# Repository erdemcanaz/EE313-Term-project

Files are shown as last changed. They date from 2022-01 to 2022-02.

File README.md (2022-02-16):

<h1 align="center" style=" border-bottom: none ;">Implementing An Analog Approach For Closed Environment Autonomous Temperature Control Circuitry </h1>
<h3 align="center" style="font-style: italic;font-size:2em;">  EE-313 TERM PROJECT </h3>

<h3 align="center" style="font-style: italic;font-size:2em;">  General requirements </h3>

<p>The project consists of five units; namely, <b>sensing, set, control, operation and display units</b>. The sensing unit perceives the ambient temperature and sends this information to the control and display units. Similarly, set unit receives an input from the user indicating the desired temperature level and send this information to control and display units. Control unit compares the two temperatures and decides the action to be taken by the operation unit. Operation unit is where the heating and cooling systems are present. It perates one of these systems according to the signal sent from the control unit. Display unit shows the ambient and set temperatures by mapping them into a color spectrum</p>

<p align="center" width="100%">   
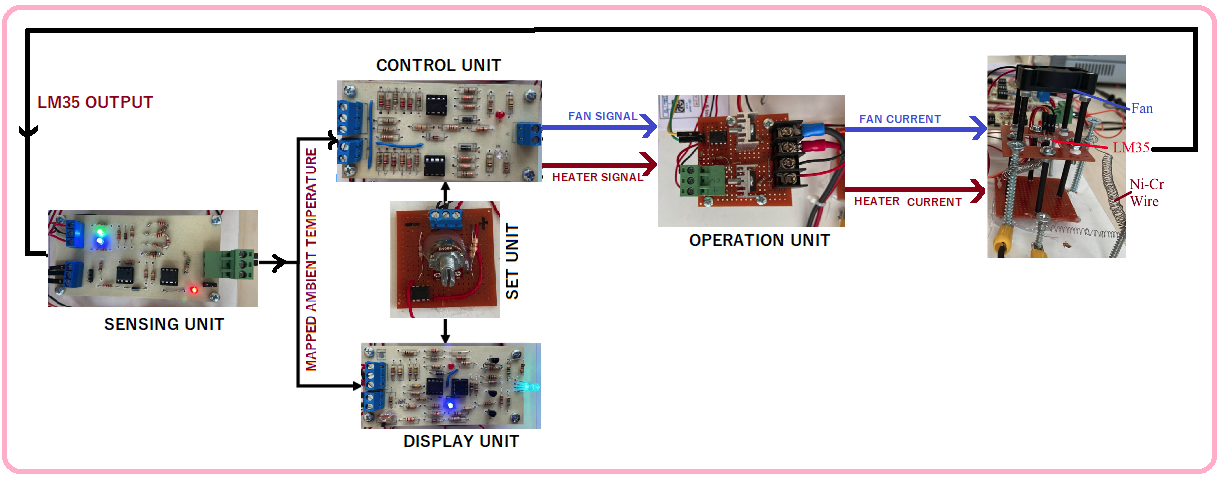
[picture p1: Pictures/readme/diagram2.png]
    <b> </b>
</p>

<h3 align="center" style="font-style: italic;font-size:2em;"> Sensing Unit </h3>

<p align="center" width="100%">   
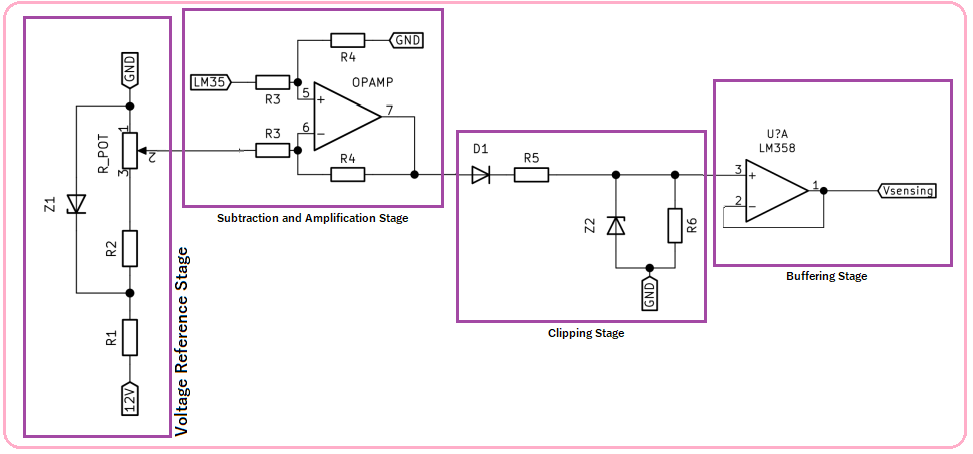
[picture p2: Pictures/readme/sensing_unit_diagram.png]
     
</p>
 
<p> Sensing unit output voltage (Vsensing) is 0V and 9V voltage for the 24◦C and 40◦C temperatures, respectively. Between these temperature levels, it has a linear increase in the output voltage. Outside of this temperature range, it performs clipping in the voltage levels. The temperature sensor used (LM35) has lienar characteristics and outputs 240mV and 400mv for 24◦C and 40◦C temperatures respectively. By subtracting 240mV and multiplying the result with 56 (160 mV x 56=8.96V), we can get desired output characteristics. Yet another problem to solve is to constrain this voltage in between 0-9Volts. Which can be done by a diode an a 9.1V zenner diode.
   <ol>
   <li><b> Voltage Reference Stage:</b> At this stage, about 240mV+(0.7)/56 is generated. 240mV is due to LM35 and (0.7)/56 is due to forward voltage drop of diode D1. Even though R3 & R4 is >> R1,R2 % R_POT; this voltage reference is not isolated. Also forward votlage drop of the diode may not be exactly 0.7Volts. Thus, a potentiometer is used to find exact point where output is 0 volt at 24C and starts to increase just after that. Then, potentiometer is replaced by resistors. </li>
   <li><b> Subtraction and Amplification Stage:</b> At this stage, reference voltage is subtracted froum LM35 voltage output. The result is multiplied by the ratio of R4/R3. We chosed R4/R3 as 56.</li>
   <li><b> Clipping Stage:</b> This stage rectifies the output of the subtraction stage due to <b>D1</b>. And if voltage of the previous stage is greater than <b>V_Z2</b>, <b> Z2</b> is activated and voltage upper limit is set.</li>
   <li><b> Buffering Stage:</b> This stage buffers the output.</li>
   </ol> 
   Experimentally measured input output characteristics and stability of the reference stage due to unstable buss voltage are given below.   
</p> 

<p align="center" width="100%">   
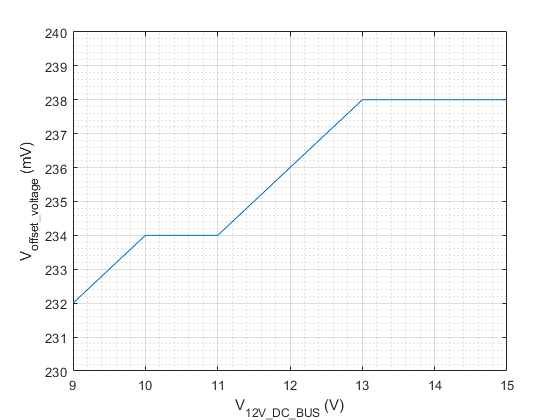
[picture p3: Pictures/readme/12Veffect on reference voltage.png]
     
</p>
<p align="center" width="100%">   
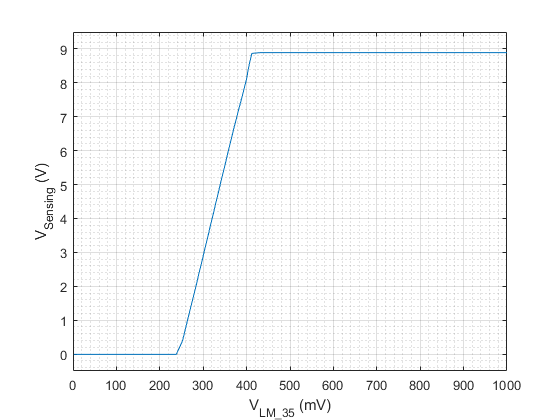
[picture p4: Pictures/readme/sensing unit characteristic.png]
     
</p>

<h3 align="center" style="font-style: italic;font-size:2em;"> Set Unit </h3>
Desired temperature is set by adjusting the the potentiometer's knob. The schematic is self explanatory. <b> R1, R2 and R_POT</b> ensures voltage of the second leg of the potentiometer is greater than 0.25V and less than 8.75V. 
<p align="center" width="100%">   
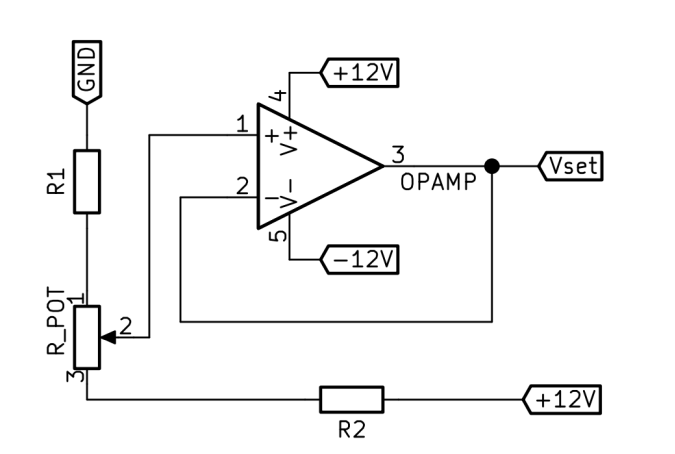
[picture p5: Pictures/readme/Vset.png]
     
</p>
<b> </b>

<h3 align="center" style="font-style: italic;font-size:2em;"> Control Unit </h3>

<p align="center" width="100%">   
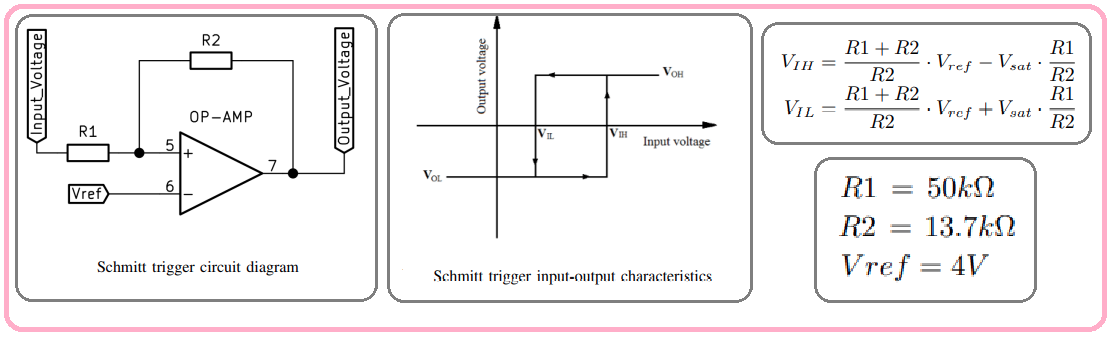
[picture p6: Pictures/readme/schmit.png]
     
</p>
<p align="center" width="100%">   
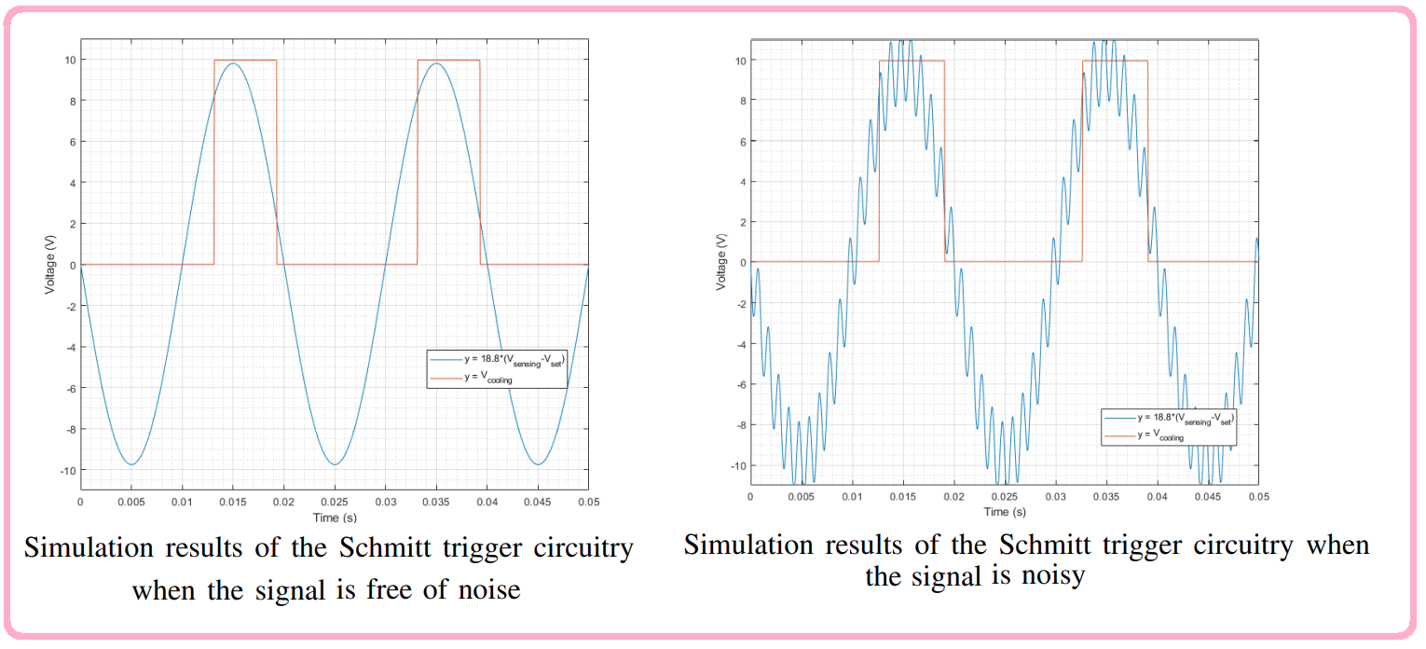
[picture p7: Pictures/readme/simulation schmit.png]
     
</p>

<h3 align="center" style="font-style: italic;font-size:2em;"> Operation Unit: Heating and Cooling </h3>
<h3 align="center" style="font-style: italic;font-size:2em;"> Display Unit </h3>

<h1 align="center" style=" border-bottom: none ;">THANKS! </h1>

<p align="center" width="100%">   
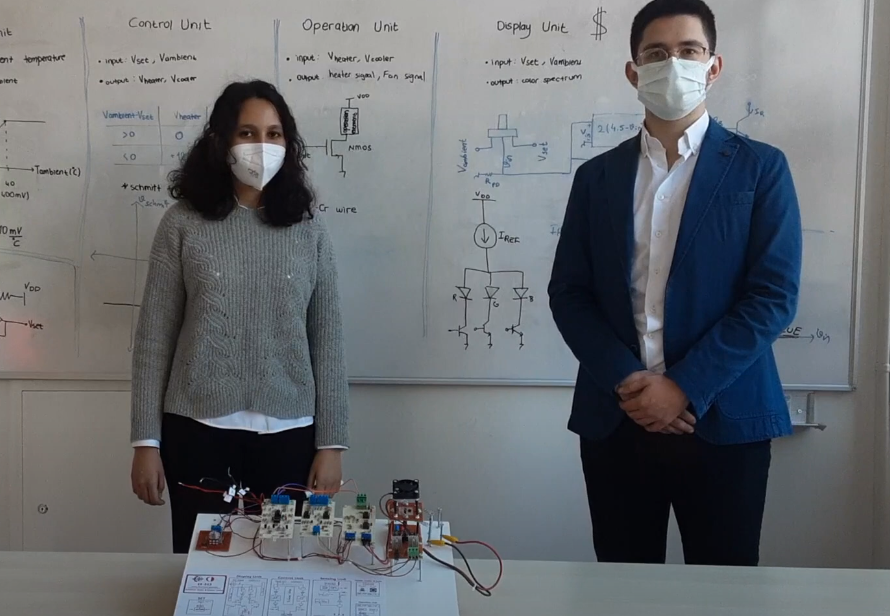
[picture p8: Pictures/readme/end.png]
     
</p>

<p align="center" width="100%">   
   <b>Semanur Avşar</b> (Left) & <b>Erdem Canaz</b>  (right) <br>   https://youtu.be/WysXOD-1qQ8
</p>

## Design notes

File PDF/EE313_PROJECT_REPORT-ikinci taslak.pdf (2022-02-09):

# Implementing An Analog Approach For Closed Environment Autonomous Temperature Control Circuitry

1

st Semanur Avs¸ar
Electrical and Electronics Engineering Dept. Middle East Technical University Ankara, Turkey
s.avsar01@gmail.com

2

nd Erdem Canaz
Electrical and Electronics Engineering Dept. Middle East Technical University Ankara, Turkey
erdemcanaz@gmail.com

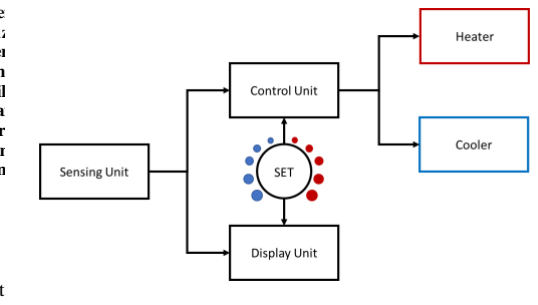
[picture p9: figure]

Abstract—*˙Is¸te konforlu bi c¸alıs¸ma ortamı ic¸in ofislerden evlere, her yerde bulundugumuz iklimi kontrol altında tutmalıyız. ˘ uygun olmayan sıcaklık ve neme sahip ortamlar c¸alıs¸ma per-formansını dus¸¨ urebilir ve konforu azaltabilir. Bu sebeple klima ¨ kopntrol uniteleri falan elzem. Bu is¸lemi dijital circuitlar ile ¨ kolay bir s¸ekilde yapabiliriz fakat analog circuitlar ile yapmaktan daha maliyetli olabilir. Biz bu projede tamamen analog temellere
dayanan ve aldıgı sıcaklık ˘ | olc¸ ¨ umlerine g ¨ | ore ısıtıcıyı veya fanı ¨
c¸alıs¸tırarak sıcakıgı belli bir aralıkta tutan bir proje ˘ | uzerine ¨
c¸alıs¸tık.
Index Terms—
I. INTRODUCTION

Whether it is an office, home or a restaurant the climate should kept under control for establishing comfort. Air conditioners provide this with heating, cooling or humidifying operations. Most of the air conditioners are digital hence have some limittions. Designing a digital air conditioner is

II. PROBLEM DEFINITION

In this project, design and implementation of a micro air conditioner will be discussed. The function of the conditioner is either heating and cooling. It compares the ambient temperature with the desired temperature. If the ambient temperature is less than the desired temperature, it operates the heating mode. Otherwise it operates the cooling mode. The project consists of four units; namely, sensing, control and operation and display units. The sensing unit perceives the ambient temperature and sends this information to the control unit. Also, there is another designed a simple circuit to take the information of desired temperature. This unit also sends its output to the control unit. Control unit compares the two temperatures and decides the action to be taken by the operation unit. Operation unit is where the heating and cooling systems are. It operates one of these systems according to the signal sent from the control unit. Display unit shows the ambient and set temperature by mapping them into a color spectrum. The block diagram of the project can be seen in Figure 1.
For each of these units we had some design specifications. Details of how we achieved these specification will be given

Fig. 1. Block diagram of the micro air conditioner

in the related section, however we provide those specifications here for the sake of completeness.
- abc

III. UNIT OPERATIONS

In this section, first, proposed way of designing the units are explained. Then, simulation and experimental results are shared. Finally, findings are discussed. For the simulations, LTspice is used and its results are plotted using MATLAB. In the circuits, the DC supply’s ±25V terminals are arranged to provide ±12V and used along with the GND connection to drive the circuits.

A. Sensing Unit

Sensing unit converts the ambient temperature into a DC voltage signal which the control unit can process. Output of this unit is 0V and 9V voltage for the 24◦C and 40◦C temperatures, respectively. Between these temperature levels, it has a linear increase in the output voltage. Outside of this temperature range, it performs clipping in the voltage levels. First discussion on the sensing unit was to select a temperature sensor. With the price and linearity properties considered,

LM35 was decided to use.LM35 has three terminals corresponding to supply voltage, ground, and output voltage. By supplying it with 4V to 20V , its output terminals relation with the ambient temperature is given in the Equation 1 [1]

Vout = 0mV + 10

mV

◦C

(1)

12V and ground terminals of the power supply is connected to LM35. Using the output of LM35, four specifications mentioned above had to be attained. First, to have 0V when the ambient temperature is 24◦C offset voltage of 10mV /◦C ∗ 24◦C = 240mV had to be eliminated. Then, since LM35 gives an increase of 10mV /◦C∗(40−24)◦C = 160mV between the temperature range, the signal should be amplified 9V 160mV ≈ 56 times. To obtain the offset voltage value, the voltage divider circuit in Figure 2 is used. Here, the Zener diode is used as a voltage regulator to avoid possible oscillations of the voltage source. The voltage on the Zener diode is divided using resistors, and the voltage on the one of the resistors are taken. In the following parts, a diode is used in the circuit. Hence, to eliminate its voltage drop either, the resistance values are arrange to give the sum of 240mV + 700mV = 940mV as the voltage output. Then, this voltage is fed to a voltage buffer to isolate it from the rest of the circuit.

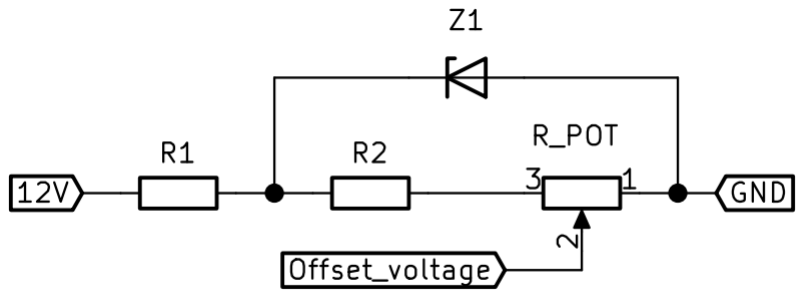
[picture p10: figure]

Fig. 2. Offset voltage to be subtracted

VAmplif ied signal =

R4
R3
- (VLM 35 − VOf f set voltage) (2)

0 ≤ Cpot ≤ 1 and 12 · (RP OT + R2) (RP OT + R2) + R1

≤ VZ1
(3)

VOf f set voltage = VZ1

·

RP OT · CP OT
R2 + RP OT

(4)

Afterwards, a difference amplifier using an opamp in Figure ?? is used. This circuit meets the need of both subtracting the offset voltage from the LM35 reading and amplifying it 56 times. The analysis of this configuration is provided in Appendix ??

VAmplif ied signal =

R4
R3
- (VLM 35 − VOf f set voltage) (5)

Then, to achieve clipping, two components are used. A diode to eliminate negative voltages and a 9V Zener diode in clipping configuration to limit the voltage level to 9V . The configuration can be seen in Figure 15. When the temperature

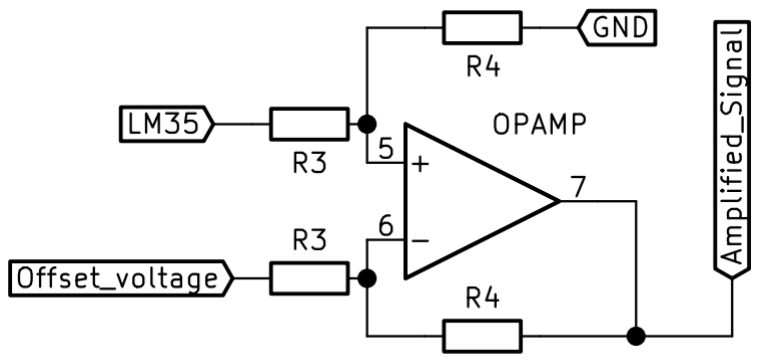
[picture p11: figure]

Fig. 3. Difference amplifier with a gain of R4/R3

level is below the 24◦C, the amplified signal obtained from the difference amplifier is negative. Then, the diode does not allow any current flow on it resulting in 0V in its other end. When it is larger than 9 V, the Zener diode clips the voltage across is to 9V . The ratio of the resistance values are taken to be high in order to not lose the amplified signals value on the resistor series to it much.

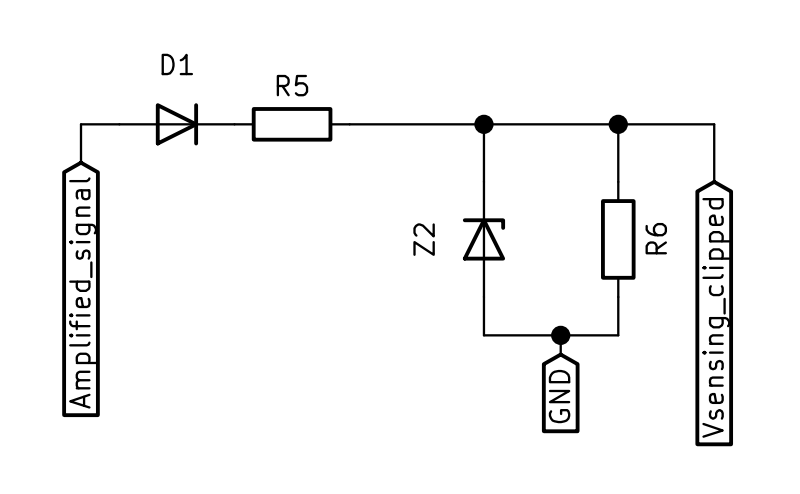
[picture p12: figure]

Fig. 4. Clipping circuit

Vsensing clipped = (VAmplif ied signal − VD1 ON )·(

R6
R5 + R6

)

(6)
Consider R5 << R6 and VAmplif ied signal = VAS;

Vsensing clipped =

0V | if VAS < VD1 ON
VZ2 | if VAS − VD1 ON > VZ2
VAS − VD1 ON | if Otherwise
(7)
Then, this voltage is again fed to a voltage buffer, and the output of the buffer is the overall output of this unit which is denoted as Vsensing. The change in the output voltage with respect to the ambient temperature is given in equation 8
Vsensing = 0.56(Cambient − 24)V | (8)

Apart from the function of the system, some LED lights are added to the circuit to verify the correct operation. To observe the output voltage level without affecting the circuit in Figure ?? is used where the current through the LED is controlled by the output voltage level. This allows to check the output voltage level by observing the LED lights intensity.

Vsensing = Vsensing clipped | (9)

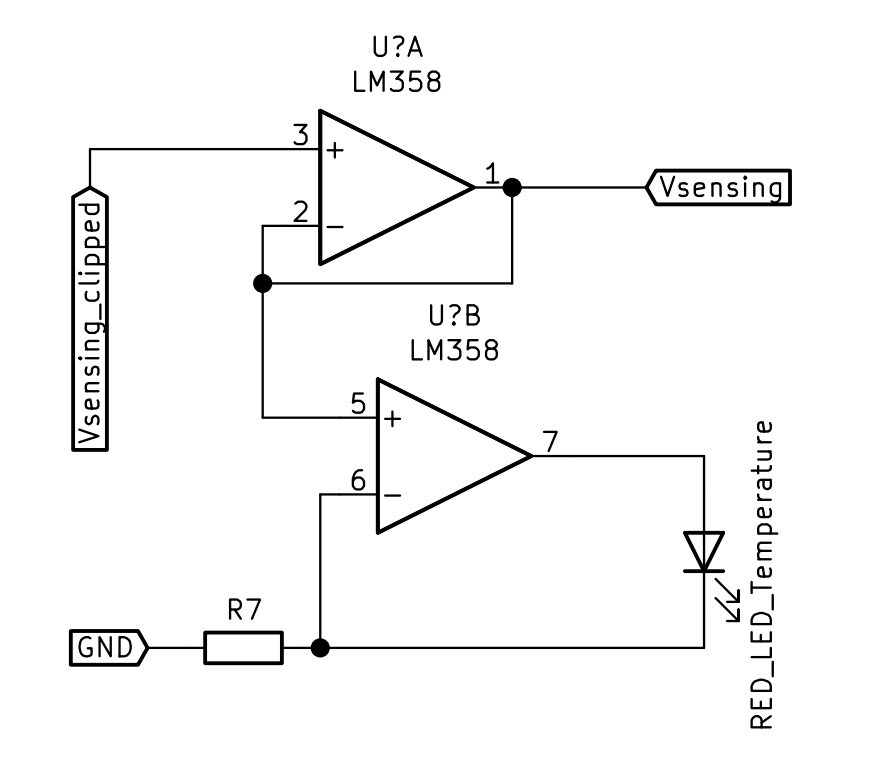
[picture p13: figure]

Fig. 5. Buffering Vsensing clipped, and Vsensing magnitude indicating

IRED LED T emperature =

Vsensing
R7

(10)

So by combining equations xxxxxxx

Vsensing =

R4
R3
- (VLM 35 − VOf f set voltage) (11)

Also, the DC power supply terminals are connected to LED lights through resistors to verify the proper connection of those terminals. Configuration of this part can be seen in Figure ??.

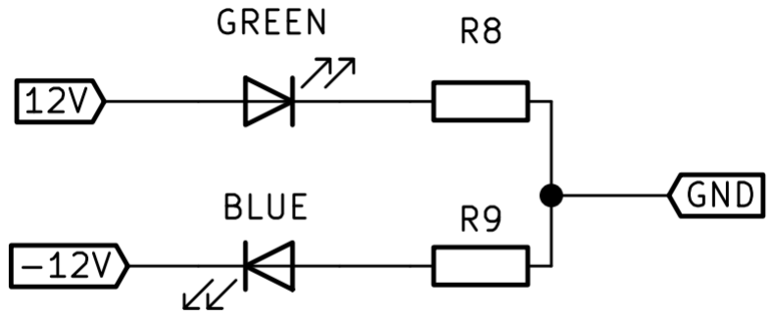
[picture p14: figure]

Fig. 6. +12V, GND and -12V indicator LEDs

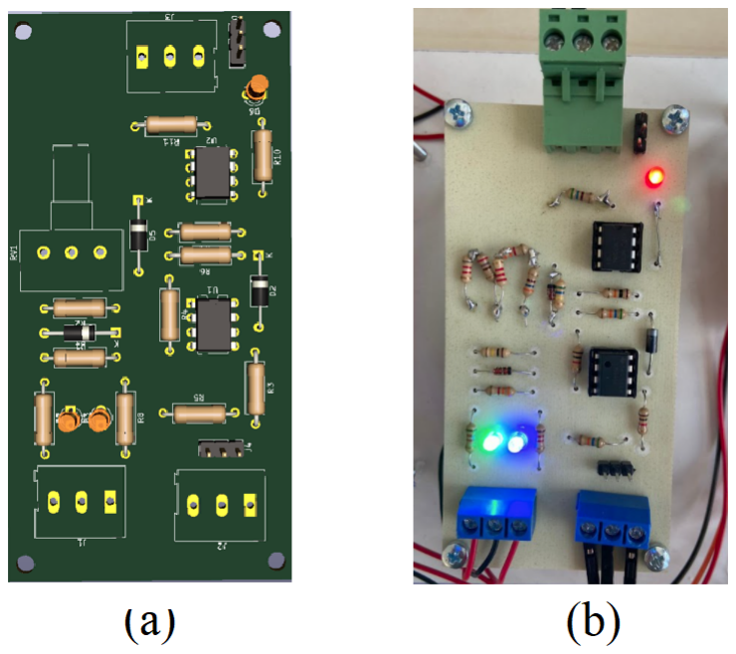
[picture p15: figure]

Fig. 7. Designed (a) & assembled (b) PCBs of the sensing unit.

B. Set Unit
Set unit is where the user specifies the desired temperature. This unit is responsible of converting the desired temperature level into a voltage signal which to be compared with the sensing units output. To achieve this, a basic circuit with a potentiometer is utilized. User can control the knob of the potentiometer until the desired temperature level’s color is observed at the display unit. Since the sensing unit gives output between the 0 and 9V , same voltage range should be available in the set unit either. To achieve this, the circuit in the Figure 8 is designed. The output voltage level is taken from the middle leg of the potentiometer. This assures a linear increase in the voltage level when the knob is turned. Ideally, 0V output voltage is wished when the potentiometer gives 0Ω between its middle and lower legs. Hence the R? resistance should be chosen 0. But, to compensate for possible unidealities in the sensing units output voltage, minimum output voltage of this unit is chosen to be 0.25V . Similarly, maximum output voltage is chosen to be 8.75V . Hence the resistance values are chosen accordingly. The opamp is used as a buffer for isolation purposes. Similar to the sensing unit, the relation between the output of this unit and the set temperature is given in the equation 12.
Vset = 0.56(Cset − 24)V | (12)

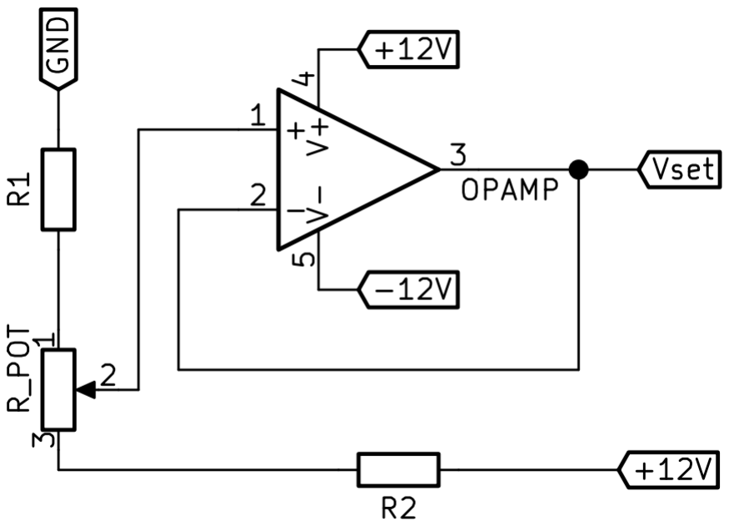
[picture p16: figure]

Fig. 8. Schematic of the set unit

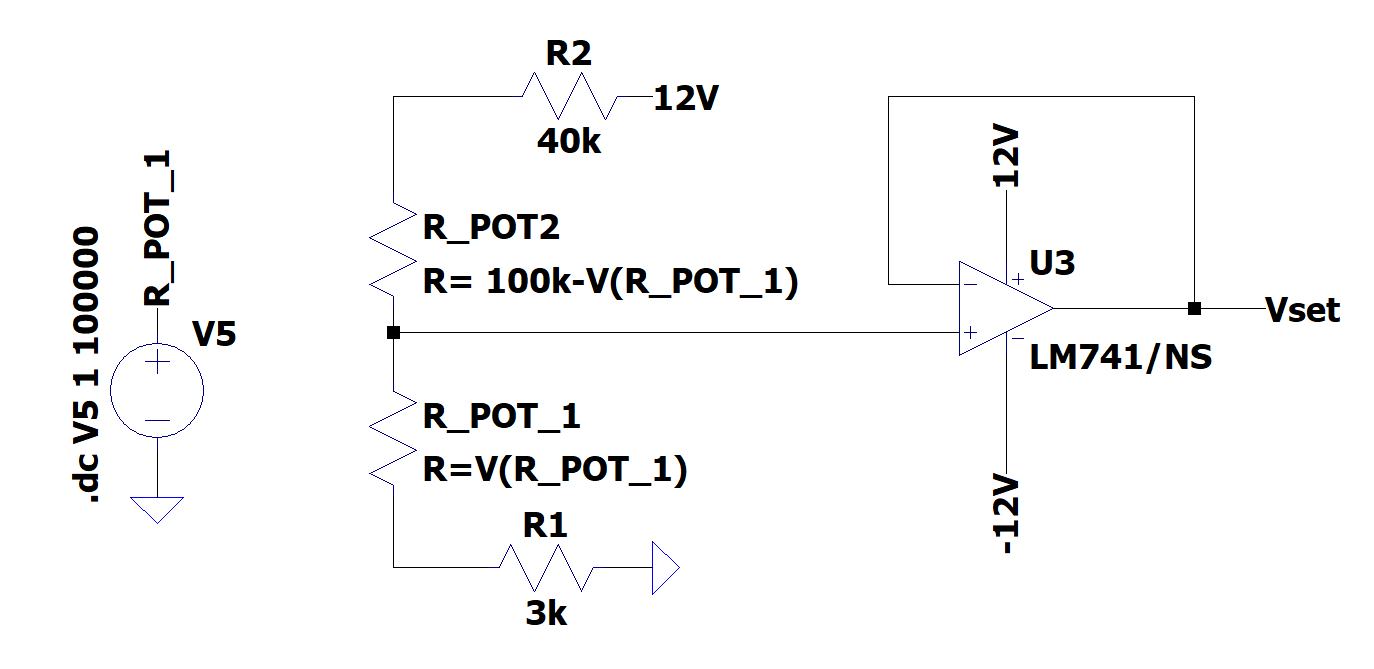
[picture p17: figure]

Fig. 9. LTspice model of the set unit

C. Control Unit

Control unit is where the signals from the set and sensing units are compared and the corresponding action ,heating or cooling, is determined. This unit takes two inputs Vsensing and Vset and produces two outputs Vheating and Vcooling. The desired relation between these signals are given in the Table II where Vrest and Voperate are chosen to be 0 and 12V respectively.

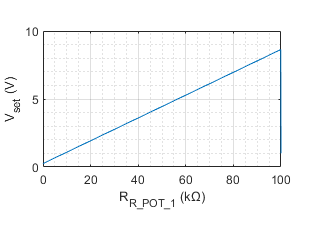
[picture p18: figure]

Fig. 10. LTspice simulation results of the set unit

TABLE I
INPUT OUTPUT RELATIONS OF THE CONTROL UNIT
Vsensing − Vset | > 0 | < 0 | = 0
Vheater | Vrest | Voperate | Vrest
Vcooler | Voperate | Vrest | Vrest

First step of this unit is taking the difference of the Vset and Vsensing. A difference amplifier in Figure ?? can be used for this action. While making the subtraction, the resistance values are chosen to give a gain of 18.8. Using this gain and 8 and 12, the relation between Vset − Vsensing and the temperature difference between the ambient and set temperature reduces to the equation 13 which means each 10V in the output voltage of the difference amplifier corresponds to 1

◦C difference between
the ambient and set temperatures which is easy to work with.
Vset − Vsensing = 10(Cset − Csensing)V | (13)

To obtain the relation in table II from the output of the difference amplifier, a comparator should be utilized. But using a basic comparator can make the system vulnerable for oscillations between heating and cooling operations. Hence, schmitt trigger topology is chosen to apply. Schmitt trigger is a circuit topology that can be implemented with an opamp which has the vin vs vout characteristics in Figure 11.

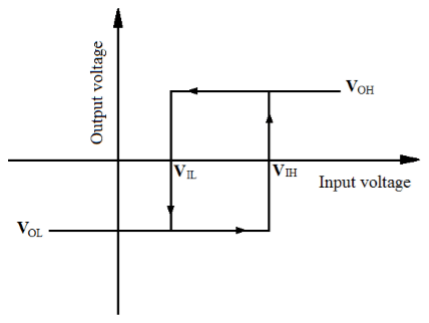
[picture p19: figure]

Fig. 11. Schmitt trigger

A normal comparator characteristics has a change in the output voltage at just one point which makes it unstable around that input voltage value. This characteristics does not have that problem since it requires VIH amount of input voltage to have VOH amount of output voltage but the output voltage does not change unit the input voltage is reduced to VIL. Circuit implementation of the schmitt trigger is given in Figure ?? Here, by substituting the output voltage of the difference amplifier as the input value, the resistance values can be chosen such that the output voltage???? Here, Vref is ??. Desired Vref can be obtained from the circuit in Figure ??. This circuit is very similar to the one used at the sensing unit to obtain the offset voltage in Figure 2. There is a zener diode to suppress the oscillations in the power supply and a voltage divider circuit between its tips. The resistance values are chosen to give ??V as the reference voltage.
As a last step, circuit in Figure ?? is used. The output of the schmitt trigger is passed through a diode and connected to the ground through a resistor to make the negative voltages
0. Also, the output from the diode is connected to a red led to indicate the operation element is working. As can be seen from the Figure ??, voltage at the tip of the diode is the overall output.
Note that there are two circuits in this unit. Output of one of which is producing Vheating and the other one is producing Vcooling. The diagram of both of these circuits are the same and explained above except for the subtraction direction in the difference amplifier. For Vheating, Vsensing is subtracted from the Vset as explained above. For Vcooling, Vset is subtracted from the Vsensing.

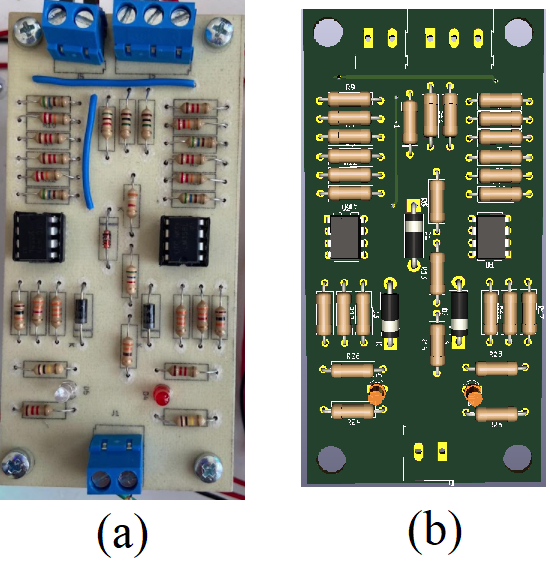
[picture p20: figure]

Fig. 12. Designed (a) & assembled (b) PCBs of the control unit.

D. Operation Unit: Heating and Cooling

Operation unit is isolating the power circuitry from the rest of the design. It is responsible for conducting the specified operation by the control unit. This unit has two input terminals corresponding to the output terminals of the control unit for heating and cooling operation.As explained in the related section, control unit sends Voperate = 5V for the operation it wants to take place and Vrest = 0V for the one it does not. Hence, this unit should act like a switch for the heating and cooling elements which is on when the input is 5V and off when it is 0V . As the heating element, nickel-chromium resistance wire is used. This choice was made due to low heat capacity of this element which allows fast starting and finishing heating. As the cooling element, 9V DC computer case fan is used. The heating and cooling circuits are two separate circuits having one input but their configurations are the same except the operation element used. In this circuit configuration, first, the input voltage is transferred using a voltage buffer for isolation purposes. Then the output of the voltage buffer is fed into the gate of a MOSFET whose drain is connected to the voltage supply through the heating/cooling element. The source of the MOSFET is connected to the ground. A large resistance between the ground and source terminals of the MOSFET is connected. This resitor is put for reliability issues, it stabilizes the amplifier. The MOSFET has opening VGS,op voltage as ???V This is compatible with the possible input voltage values. Since VGS,op is fairly bigger than Voperate and smaller than Vrest, small discrepancies will not affect the operation of the circuit. Also, another resistance is added between the input signal and the ground to avoid a floating end when the input signal is not connected. When Voperate is supplied, the MOSFET is out of the cut-off region. Hence, drain current is allowed to flow on it. Since the drain of the MOSFET is connected to the operation element, the operation element works for this case. When Vrest is supplied, the MOSFET is in the cut-off region. Hence, drain current is not allowed to flow and the operation element does not work. The overall structure can be seen in Figure 13
add figure here

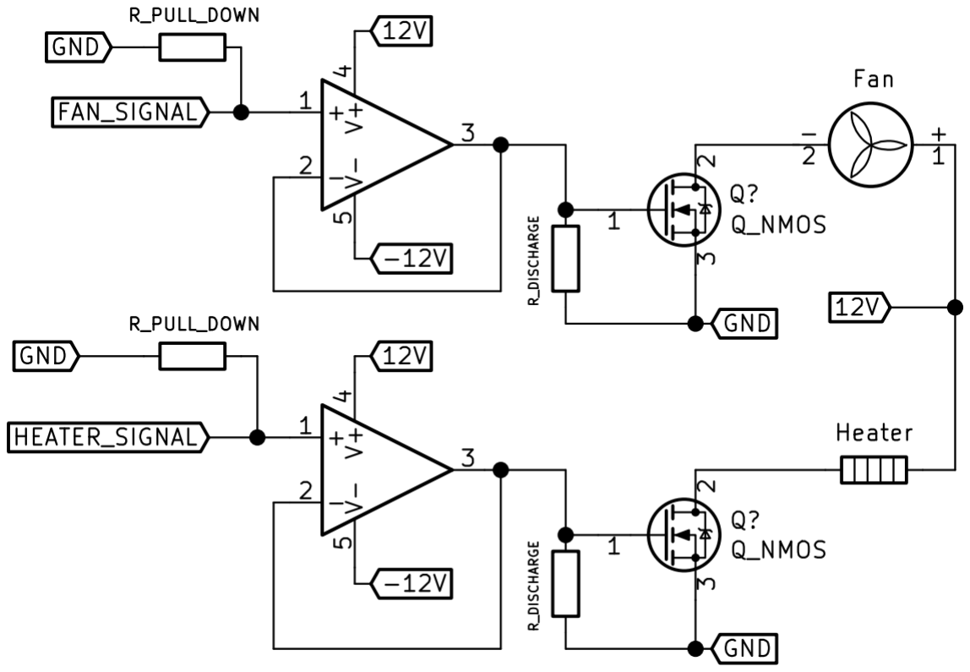
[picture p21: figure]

Fig. 13. Schematic of the operation unit

TABLE II
ELECTRICAL CHARACTERISTICS OF FAN AND HEATER
Unit Name | Current(mA) | Voltage Drop (V) | Power(W)
Fan simulated | 150 | 12 | 1.8
Fan practical | 78 | 12 | 0.94
Heater simulated | 500 | 12 | 6
Heater practical | 620 | 12 | 7.4
E. Display Unit
The aim of the display unit is to observe the desired and ambient temperature levels in a color spectrum in an analog manner given in the Figure 16. Input of this unit is both

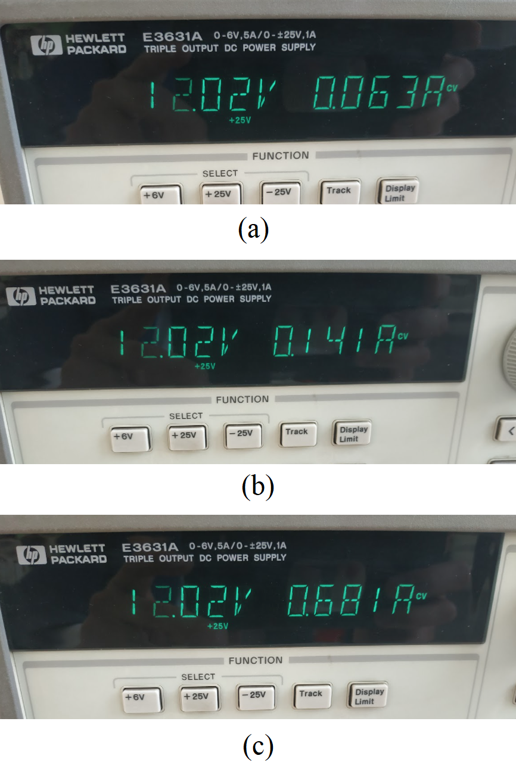
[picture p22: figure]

Fig. 14. Input current & input voltage characteristics of the system when neither fan nor heater is working (a), fan is working (b), heater is working (c)

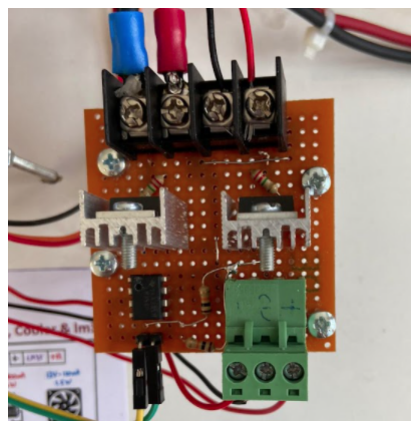
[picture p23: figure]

Fig. 15. Assembled operation unit

Vset and Vsensing. But only one of the input is considered at a time. A switch is utilized to transit between ambient and set temperature levels. In the remaining of this section, only ambient temperature will be discussed to ease the notations. It should be noted that, same operation applies to the set temperature when the swith is in the corresponding position. To achieve a continuous color spectrum, an RGB led is utilized. RGB led has three legs corresponding to blue, green and red led lig!hts whose intensities can be controlled by the current passing through them. RGB led has two versions: common cathode and common anode. [2] *niye common cathode sec¸ildigini ac¸ıkla ˘
Since the current and intensity of the led lights are directly proportional, current through each three led versus the temperature graphs should be as the Figure ??. To achieve this pattern for the red led leg, first, the circuit in Figure 17 is designed. What this circuit does it to produce a voltage level, denoted by Vred. Later, voltage level will be fed to the base terminal

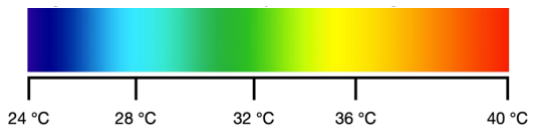
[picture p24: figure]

Fig. 16. Color spectrum for the display unit

of a BJT through a resistor to control the current entering the collector terminal of the BJT. The circuit in Figure 17 consists of a difference amplifier, a diode and a pull down resistor to eliminate the output when it is negative and a led to verify the positive output voltage. By using the equations 8 and 12 and inserting this into the Figure 14’s temperature axis it can be seen that red led should not allow any current when the input voltage (Vsensing) is less than 4.5V . Hence, the reference value to be substracted from the input should be 4.5V . Output Vred voltage of this circuit is given in the equation 14.

Vred =

(
R?
R?

(Vin − Vref − 0.5Vdiode) if Vred > 0
0 | o. w.

(14)

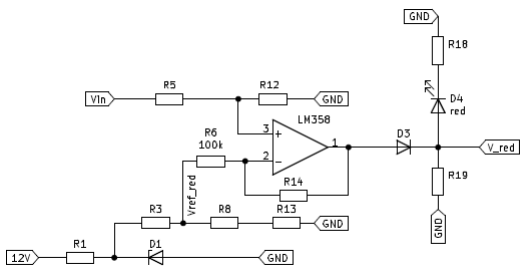
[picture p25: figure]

Fig. 17. Color spectrum for the display unit

A similar logic can be applied to obtain a Vblue voltage. This time blue led should not allow any current when the input voltage (Vsensing) is more than 4.5V . Hence, the circuit in the Figure 18 is constructed to obtain Vblue to be fed to the base terminal of a BJT. In this circuit everything is the same with the circuit in Figure 17 expect the direction of the subtraction in the difference amplifier. Output Vblue voltage of this circuit is given in the equation 15.

Vblue =

(
R?
R?

(Vref − Vin − 0.5Vdiode) if Vblue > 0
0 | o. w.

(15)

For the current going through the green leg, we do not have a zero current region like in the blue and red legs, hence, it is difficult to implement that current level in a similar manner. But note that, the total amount of current flowing through the all three legs are equal for all temperatures. Hence current

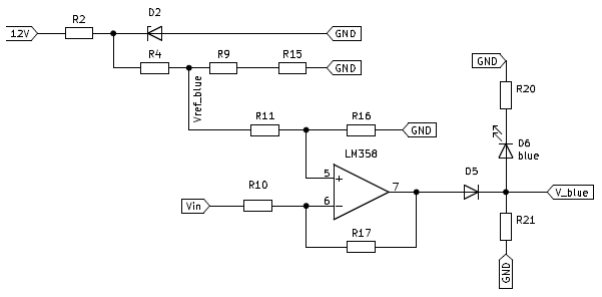
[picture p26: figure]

Fig. 18. Color spectrum for the display unit

through the red leg can be computed as Iref − Ired − Iblue where Ired and Iblue are denoting the current through the blue and red legs respectively and the Iref can be found in Figure ??.For this purpose, the circuit in the Figure ?? is constructed. This circuit acts like an ideal current source with value curentvalueintermsofR. The final circuitry of this unit can be seen in Figure 19. As explained before, Vred and Vblue voltages are fed to a base of a BJT whose emitter is connected to the ground and collector is collected to the red and green legs of the RGB led. This configuration provides a linear increase in the collector current with respect to the Vred and Vblue. Here, R22 is chosen such that 15mA of current will pass the collector of Q1 when then Vred = 10V . A similar choice of R29 is also valid. With supplying the reference current value to the overall RGB, current through the green leg is arranged. Here, it should be noted that there are actually two voltage drops on Vred and Vblue. First one is coming from the opening voltage of the diode in Figures ?? and ?? which are also explained in the equations 15 and 14. Second one is the opening voltage of the BJT in the Figure 19. Hence, with the 4.5 V of reference voltage is not enough, the reference voltages should be determined so that these voltage drops are taken into account.

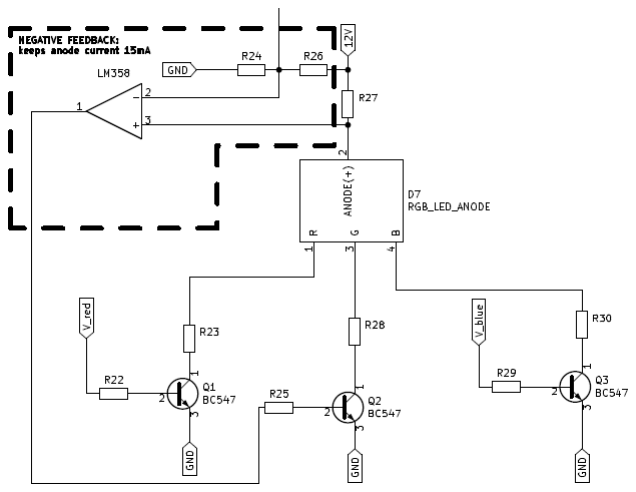
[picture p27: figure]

Fig. 19. Color spectrum for the display unit

*kullanılan mosfet ve opamp c¸es¸itlerini belirt *opampte iki opamp oldugunu belirt ˘
*simulation results
*experimental results
The input output relations of the units can be seen in Figure 20.

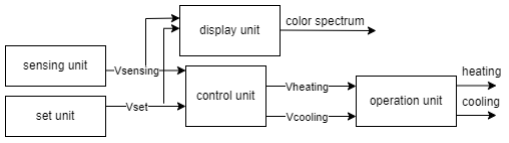
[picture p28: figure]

Fig. 20. Color spectrum for the display unit

IV. CONCLUSION

REFERENCES

[1]
[2]

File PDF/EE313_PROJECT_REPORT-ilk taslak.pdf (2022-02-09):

# Implementing An Analog Approach For Closed Environment Autonomous Temperature Control Circuitry

1

st Semanur Avs¸ar
Electrical and Electronics Engineering Dept. Middle East Technical University Ankara, Turkey
s.avsar01@gmail.com

2

nd Erdem Canaz
Electrical and Electronics Engineering Dept. Middle East Technical University Ankara, Turkey
erdemcanaz@gmail.com

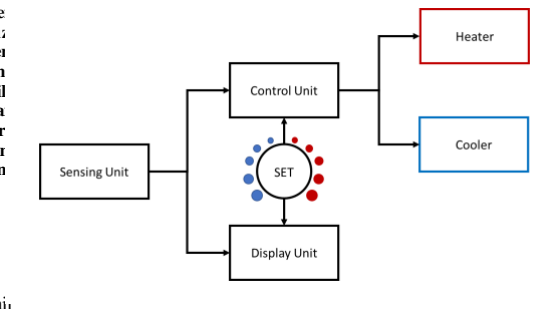
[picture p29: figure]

Abstract—*˙Is¸te konforlu bi c¸alıs¸ma ortamı ic¸in ofislerden evlere, her yerde bulundugumuz iklimi kontrol altında tutmalıyız. ˘ uygun olmayan sıcaklık ve neme sahip ortamlar c¸alıs¸ma per-formansını dus¸¨ urebilir ve konforu azaltabilir. Bu sebeple klima ¨ kopntrol uniteleri falan elzem. Bu is¸lemi dijital circuitlar ile ¨ kolay bir s¸ekilde yapabiliriz fakat analog circuitlar ile yapmaktan daha maliyetli olabilir. Biz bu projede tamamen analog temellere
dayanan ve aldıgı sıcaklık ˘ | olc¸ ¨ umlerine g ¨ | ore ısıtıcıyı veya fanı ¨
c¸alıs¸tırarak sıcakıgı belli bir aralıkta tutan bir proje ˘ | uzerine ¨
c¸alıs¸tık.
Index Terms—
I. INTRODUCTION

II. PROBLEM DEFINITION
In this project, design and implementation of a micro air conditioner will be discussed. The function of the conditioner is either heating and cooling. It compares the ambient temperature with the desired temperature. If the ambient temperature is less than the desired temperature, it operates the heating mode. Otherwise it operates the cooling mode. The project consists of four units; namely, sensing, control and operation and display units. The sensing unit perceives the ambient temperature and sends this information to the control unit. Also, there is another designed a simple circuit to take the information of desired temperature. This unit also sends its output to the control unit. Control unit compares the two temperatures and decides the action to be taken by the operation unit. Operation unit is where the heating and cooling systems are. It operates one of these systems according to the signal sent from the control unit. Display unit shows the ambient and set temperature by mapping them into a color spectrum. The block diagram of the project can be seen in Figure 1.
For each of these units we had some design specifications. Details of how we achieved these specification will be given in the related section, however we provide those specifications here for the sake of completeness.
- abc

III. UNIT OPERATIONS
In this section, first, proposed way of designing the units are explained. Then, simulation and experimental results are

Fig. 1. Block diagram of the micro air conditioner

shared. Finally, findings are discussed. For the simulations, LTspice is used and its results are plotted using MATLAB. In the circuits, the DC supply’s ±25V terminals are arranged to provide ±12V and used along with the GND connection to drive the circuits.

A. Sensing Unit

Sensing unit converts the ambient temperature into a DC voltage signal which the control unit can process. Output of this unit is 0V and 9V voltage for the 24◦C and 40◦C temperatures, respectively. Between these temperature levels, it has a linear increase in the output voltage. Outside of this temperature range, it performs clipping in the voltage levels. First discussion on the sensing unit was to select a temperature sensor. With the price and linearity properties considered, LM35 was decided to use.LM35 has three terminals corresponding to supply voltage, ground, and output voltage. By supplying it with 4V to 20V , its output terminals relation with the ambient temperature is given in the Equation 1 [1]

Vout = 0mV + 10

mV

◦C

(1)

12V and ground terminals of the power supply is connected to LM35. Using the output of LM35, four specifications mentioned above had to be attained. First, to have 0V when the ambient temperature is 24◦C offset voltage of 10mV /◦C ∗ 24◦C = 240mV had to be eliminated. Then, since LM35 gives an increase of 10mV /◦C∗(40−24)◦C = 160mV between the temperature range, the signal should be amplified 9V 160mV ≈ 56 times. To obtain the offset voltage value, the voltage divider circuit in Figure 2 is used. Here, the Zener diode is used as a voltage regulator to avoid possible oscillations of the voltage source. The voltage on the Zener diode is divided using resistors, and the voltage on the one of the resistors are taken. In the following parts, a diode is used in the circuit. Hence, to eliminate its voltage drop either, the resistance values are arrange to give the sum of 240mV + 700mV = 940mV as the voltage output. Then, this voltage is fed to a voltage buffer to isolate it from the rest of the circuit.


Fig. 2. Offset voltage to be subtracted

VAmplif ied signal =

R4
R3
- (VLM 35 − VOf f set voltage) (2)

0 ≤ Cpot ≤ 1 and 12 · (RP OT + R2) (RP OT + R2) + R1

≤ VZ1 (3)

VOf f set voltage = VZ1 ·

RP OT · CP OT
R2 + RP OT

(4)

Afterwards, a difference amplifier using an opamp in Figure 3 is used. This circuit meets the need of both subtracting the offset voltage from the LM35 reading and amplifying it 56 times. The analysis of this configuration is provided in Appendix ??

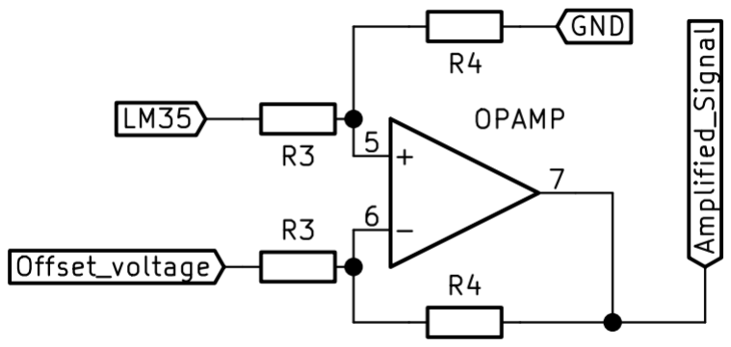
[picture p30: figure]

Fig. 3. Difference amplifier with a gain of R4/R3

VAmplif ied signal =

R4
R3
- (VLM 35 − VOf f set voltage) (5)

Then, to achieve clipping, two components are used. A diode to eliminate negative voltages and a 9V Zener diode in clipping configuration to limit the voltage level to 9V . The configuration can be seen in Figure 14. When the temperature level is below the 24◦C, the amplified signal obtained from the difference amplifier is negative. Then, the diode does not allow any current flow on it resulting in 0V in its other end. When it is larger than 9 V, the Zener diode clips the voltage across is to 9V . The ratio of the resistance values are taken to be high in order to not lose the amplified signals value on the resistor series to it much.

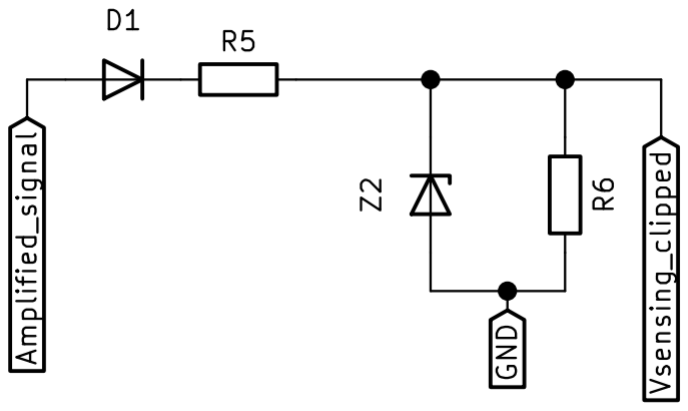
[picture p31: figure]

Fig. 4. Clipping circuit

Vsensing clipped = ( R6
R5 + R6
) − VD1 ON | (6)

Then, this voltage is again fed to a voltage buffer, and the output of the buffer is the overall output of this unit which is denoted as Vsensing. The change in the output voltage with respect to the ambient temperature is given in equation 7

Vsensing = 0.56(Cambient − 24)V | (7)

Apart from the function of the system, some LED lights are added to the circuit to verify the correct operation. To observe the output voltage level without affecting the circuit in Figure 5 is used where the current through the LED is controlled by the output voltage level. This allows to check the output voltage level by observing the LED lights intensity.


Fig. 5. ?

Also, the DC power supply terminals are connected to LED lights through resistors to verify the proper connection of those terminals. Configuration of this part can be seen in Figure 6.


Fig. 6. ?

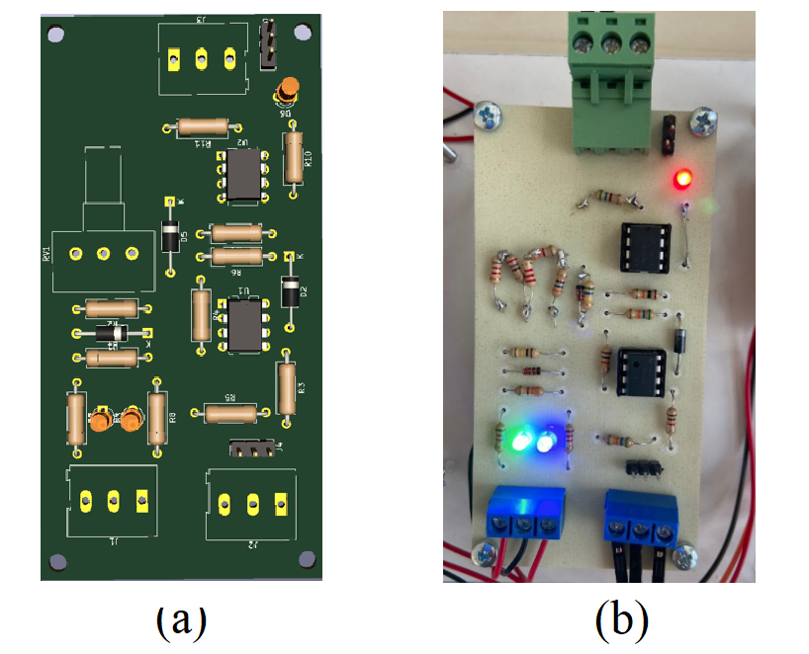
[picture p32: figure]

Fig. 7. Designed (a) & assembled (b) PCBs of the sensing unit.

B. Set Unit

Set unit is where the user specifies the desired temperature. This unit is responsible of converting the desired temperature level into a voltage signal which to be compared with the sensing units output. To achieve this, a basic circuit with a potentiometer is utilized. User can control the knob of the potentiometer until the desired temperature level’s color is observed at the display unit. Since the sensing unit gives output between the 0 and 9V , same voltage range should be available in the set unit either. To achieve this, the circuit in the Figure 8 is designed. The output voltage level is taken from the middle leg of the potentiometer. This assures a linear increase in the voltage level when the knob is turned. Ideally, 0V output voltage is wished when the potentiometer gives 0Ω between its middle and lower legs. Hence the R? resistance should be chosen 0. But, to compensate for possible unidealities in the sensing units output voltage, minimum output voltage of this unit is chosen to be 0.25V . Similarly, maximum output voltage is chosen to be 8.75V . Hence the resistance values are chosen accordingly. The opamp is used as a buffer for isolation purposes. Similar to the sensing unit, the relation between the output of this unit and the set temperature is given in the equation 8.

Vset = 0.56(Cset − 24)V | (8)


Fig. 8. Schematic of the set unit


Fig. 9. LTspice model of the set unit


Fig. 10. LTspice simulation results of the set unit

C. Control Unit

Control unit is where the signals from the set and sensing units are compared and the corresponding action ,heating or cooling, is determined. This unit takes two inputs Vsensing and Vset and produces two outputs Vheating and Vcooling. The desired relation between these signals are given in the Table II where Vrest and Voperate are chosen to be 0 and 12V respectively.

TABLE I
INPUT OUTPUT RELATIONS OF THE CONTROL UNIT
Vsensing − Vset | > 0 | < 0 | = 0
Vheater | Vrest | Voperate | Vrest
Vcooler | Voperate | Vrest | Vrest

First step of this unit is taking the difference of the Vset and Vsensing. A difference amplifier in Figure ?? can be used for this action. While making the subtraction, the resistance values are chosen to give a gain of 18.8. Using this gain and 7 and 8, the relation between Vset − Vsensing and the temperature difference between the ambient and set temperature reduces to the equation 9 which means each 10V in the output voltage of the difference amplifier corresponds to 1

◦C difference between
the ambient and set temperatures which is easy to work with.
Vset − Vsensing = 10(Cset − Csensing)V | (9)

To obtain the relation in table II from the output of the difference amplifier, a comparator should be utilized. But using a basic comparator can make the system vulnerable for oscillations between heating and cooling operations. Hence, schmitt trigger topology is chosen to apply. Schmitt trigger is a circuit topology that can be implemented with an opamp which has the vin vs vout characteristics in Figure 11.


Fig. 11. Schmitt trigger

A normal comparator characteristics has a change in the output voltage at just one point which makes it unstable around that input voltage value. This characteristics does not have that problem since it requires VIH amount of input voltage to have VOH amount of output voltage but the output voltage does not change unit the input voltage is reduced to VIL. Circuit implementation of the schmitt trigger is given in Figure ?? Here, by substituting the output voltage of the difference amplifier as the input value, the resistance values can be chosen such that the output voltage???? Here, Vref is ??. Desired Vref can be obtained from the circuit in Figure ??. This circuit is very similar to the one used at the sensing unit to obtain the offset voltage in Figure 2. There is a zener diode to suppress the oscillations in the power supply and a voltage divider circuit between its tips. The resistance values are chosen to give ??V as the reference voltage.
As a last step, circuit in Figure ?? is used. The output of the schmitt trigger is passed through a diode and connected to the ground through a resistor to make the negative voltages
0. Also, the output from the diode is connected to a red led to indicate the operation element is working. As can be seen from the Figure ??, voltage at the tip of the diode is the overall output.
Note that there are two circuits in this unit. Output of one of which is producing Vheating and the other one is producing Vcooling. The diagram of both of these circuits are the same and explained above except for the subtraction direction in the difference amplifier. For Vheating, Vsensing is subtracted from the Vset as explained above. For Vcooling, Vset is subtracted from the Vsensing.
D. Operation Unit: Heating and Cooling

Operation unit is isolating the power circuitry from the rest of the design. It is responsible for conducting the specified operation by the control unit. This unit has two input terminals corresponding to the output terminals of the control unit for heating and cooling operation.As explained in the related section, control unit sends Voperate = 5V for the operation it wants to take place and Vrest = 0V for the one it does not. Hence, this unit should act like a switch for the heating and cooling elements which is on when the input is 5V and off when it is 0V . As the heating element, nickel-chromium resistance wire is used. This choice was made due to low heat capacity of this element which allows fast starting and finishing heating. As the cooling element, 9V DC computer case fan is used. The heating and cooling circuits are two separate circuits having one input but their configurations are the same except the operation element used. In this circuit configuration, first, the input voltage is transferred using a voltage buffer for isolation purposes. Then the output of the voltage buffer is fed into the gate of a MOSFET whose drain is connected to the voltage supply through the heating/cooling element. The source of the MOSFET is connected to the ground. A large resistance between the ground and source terminals of the MOSFET is connected. This resitor is put for reliability issues, it stabilizes the amplifier. The MOSFET has opening VGS,op voltage as ???V This is compatible with the possible input voltage values. Since VGS,op is fairly bigger than Voperate and smaller than Vrest, small discrepancies will not affect the operation of the circuit. Also, another resistance is added between the input signal and the ground to avoid a floating end when the input signal is not connected. When Voperate is supplied, the MOSFET is out of the cut-off region. Hence, drain current is allowed to flow on it. Since the drain of the MOSFET is connected to the operation element, the operation element works for this case. When Vrest is supplied, the MOSFET is in the cut-off region. Hence, drain current is not allowed to flow and the operation element does not work. The overall structure can be seen in Figure 12
add figure here

TABLE II
ELECTRICAL CHARACTERISTICS OF FAN AND HEATER
Unit Name | Current Drawn (mA) | Voltage Drop (V) | Power(W)
Fan simulated | 150 | 12 | 1.8
Fan practical | 78 | 12 | 0.94
Heater simulated | 500 | 12 | 6
Heater practical | 620 | 12 | 7.4


Fig. 12. Schematic of the operation unit


Fig. 13. Input current & input voltage characteristics of the system when neither fan nor heater is working (a), fan is working (b), heater is working (c)


Fig. 14. Assembled operation unit

E. Display Unit

The aim of the display unit is to observe the desired and ambient temperature levels in a color spectrum in an analog manner given in the Figure 15. Input of this unit is both Vset and Vsensing. But only one of the input is considered at a time. A switch is utilized to transit between ambient and set temperature levels. In the remaining of this section, only ambient temperature will be discussed to ease the notations. It should be noted that, same operation applies to the set temperature when the swith is in the corresponding position. To achieve a continuous color spectrum, an RGB led is utilized. RGB led has three legs corresponding to blue, green and red led lights whose intensities can be controlled by the current passing through them. RGB led has two versions: common cathode and common anode. [2] *niye common cathode sec¸ildigini ac¸ıkla ˘


Fig. 15. Color spectrum for the display unit

Since the current and intensity of the led lights are directly proportional, current through each three led versus the temperature graphs should be as the Figure ??. To achieve this pattern for the red led leg, first, the circuit in Figure ?? is designed. What this circuit does it to produce a voltage level, denoted by Vred. Later, voltage level will be fed to the base terminal of a BJT through a resistor to control the current entering the collector terminal of the BJT. The circuit in Figure ?? consists of a difference amplifier, a diode and a pull down resistor to eliminate the output when it is negative and a led to verify the positive output voltage. By using the equations 7 and 8 and inserting this into the Figure 10’s temperature axis it can be seen that red led should not allow any current when the input voltage (Vsensing) is less than 4.5V . Hence, the reference value to be substracted from the input should be 4.5V . Output Vred voltage of this circuit is given in the equation ??.

Vred =

(
R?
R?

(Vin − Vref − 0.5Vdiode) if Vred > 0
0 | o. w.

(10)

A similar logic can be applied to obtain a Vblue voltage. This time blue led should not allow any current when the input voltage (Vsensing) is more than 4.5V . Hence, the circuit in the Figure ?? is constructed to obtain Vblue to be fed to the base terminal of a BJT. In this circuit everything is the same with the circuit in Figure ?? expect the direction of the subtraction in the difference amplifier. Output Vblue voltage of this circuit is given in the equation 11.

Vblue =

(
R?
R?

(Vref − Vin − 0.5Vdiode) if Vblue > 0
0 | o. w.

(11)

For the current going through the green leg, we do not have a zero current region like in the blue and red legs, hence, it is difficult to implement that current level in a similar manner. But note that, the total amount of current flowing through the all three legs are equal for all temperatures. Hence current through the red leg can be computed as Iref − Ired − Iblue where Ired and Iblue are denoting the current through the blue and red legs respectively and the Iref can be found in Figure ??.For this purpose, the circuit in the Figure ??
*kullanılan mosfet ve opamp c¸es¸itlerini belirt
*opampte iki opamp oldugunu belirt ˘
*simulation results
*experimental results

IV. CONCLUSION

REFERENCES

[1]
[2]

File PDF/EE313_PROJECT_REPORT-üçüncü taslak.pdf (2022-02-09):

# Implementing An Analog Approach For Closed Environment Autonomous Temperature Control Circuitry

1

st Semanur Avs¸ar
Electrical and Electronics Engineering Dept. Middle East Technical University Ankara, Turkey
s.avsar01@gmail.com

2

nd Erdem Canaz
Electrical and Electronics Engineering Dept. Middle East Technical University Ankara, Turkey
erdemcanaz@gmail.com

Abstract—*˙Is¸te konforlu bi c¸alıs¸ma ortamı ic¸in ofislerden evlere, her yerde bulundugumuz iklimi kontrol altında tutmalıyız. ˘ uygun olmayan sıcaklık ve neme sahip ortamlar c¸alıs¸ma per-formansını dus¸¨ urebilir ve konforu azaltabilir. Bu sebeple klima ¨ kopntrol uniteleri falan elzem. Bu is¸lemi dijital circuitlar ile ¨ kolay bir s¸ekilde yapabiliriz fakat analog circuitlar ile yapmaktan daha maliyetli olabilir. Biz bu projede tamamen analog temellere


dayanan ve aldıgı sıcaklık ˘ | olc¸ ¨ umlerine g ¨ | ore ısıtıcıyı veya fanı ¨
c¸alıs¸tırarak sıcakıgı belli bir aralıkta tutan bir proje ˘ | uzerine ¨
c¸alıs¸tık.
Index Terms—
I. INTRODUCTION

Whether it is an office, home or a restaurant the climate should kept under control for establishing comfort. Air conditioners provide this with heating, cooling or humidifying operations. Most of the air conditioners are digital hence have some limittions. In this project, an air conditioner based solely on analog basis is designed and implemented. This air conditioner employs heating and cooling operations by comparing the ambient and the desired tempertures. For this, 4 total of 5 units are used. Each unit had predetermined specifications. In this paper,the details of degin and implementations of these unit as well as the simulation and experimental results will be shared.

II. PROBLEM DEFINITION

In this project, design and implementation of a micro air conditioner will be discussed. The function of the conditioner is either heating and cooling. It compares the ambient temperature with the desired temperature. If the ambient temperature is less than the desired temperature, it operates the heating mode. Otherwise it operates the cooling mode. The project consists of four units; namely, sensing, control and operation and display units. The sensing unit perceives the ambient temperature and sends this information to the control unit. Also, there is another designed a simple circuit to take the information of desired temperature. This unit also sends its output to the control unit. Control unit compares the two temperatures and decides the action to be taken by the operation unit. Operation unit is where the heating and cooling systems are. It operates one of these systems according to the signal sent from the control unit. Display unit shows the ambient and set temperature by mapping them into a color spectrum. The block diagram of the project can be seen in Figure 1.

Fig. 1. Block diagram of the micro air conditioner

For each of these units we had some design specifications. Details of how we achieved these specification will be given in the related section, however we provide those specifications here for the sake of completeness.
- abc

III. UNIT OPERATIONS
In this section, first, proposed way of designing the units are explained. Then, simulation and experimental results are shared. Finally, findings are discussed. For the simulations, LTspice is used and its results are plotted using MATLAB. In the circuits, the DC supply’s ±25V terminals are arranged to provide ±12V and used along with the GND connection to drive the circuits.
A. Sensing Unit
Sensing unit converts the ambient temperature into a DC voltage signal which the control unit can process. Output of this unit is 0V and 9V voltage for the 24◦C and 40◦C temperatures, respectively. Between these temperature levels, it has a linear increase in the output voltage. Outside of this temperature range, it performs clipping in the voltage levels. First discussion on the sensing unit was to select a temperature sensor. With the price and linearity properties considered, LM35 was decided to use.LM35 has three terminals corresponding to supply voltage, ground, and output voltage. By supplying it with 4V to 20V , its output terminals relation with the ambient temperature is given in the Equation 1 [1]

Vout = 0mV + 10

mV

◦C

(1)

12V and ground terminals of the power supply is connected to LM35. Using the output of LM35, four specifications mentioned above had to be attained. First, to have 0V when the ambient temperature is 24◦C offset voltage of 10mV /◦C ∗ 24◦C = 240mV had to be eliminated. Then, since LM35 gives an increase of 10mV /◦C∗(40−24)◦C = 160mV between the temperature range, the signal should be amplified 9V 160mV ≈ 56 times. To obtain the offset voltage value, the voltage divider circuit in Figure 2 is used. Here, the Zener diode is used as a voltage regulator to avoid possible oscillations of the voltage source. The voltage on the Zener diode is divided using resistors, and the voltage on the one of the resistors are taken. In the following parts, a diode is used in the circuit. Hence, to eliminate its voltage drop either, the resistance values are arrange to give the sum of 240mV + 700mV = 940mV as the voltage output. Then, this voltage is fed to a voltage buffer to isolate it from the rest of the circuit.


Fig. 2. Offset voltage to be subtracted

VAmplif ied signal =

R4
R3
- (VLM 35 − VOf f set voltage) (2)

0 ≤ Cpot ≤ 1 and 12 · (RP OT + R2) (RP OT + R2) + R1

≤ VZ1
(3)

VOf f set voltage = VZ1

·

RP OT · CP OT
R2 + RP OT

(4)

Afterwards, a difference amplifier using an opamp in Figure ?? is used. This circuit meets the need of both subtracting the offset voltage from the LM35 reading and amplifying it 56 times. The analysis of this configuration is provided in Appendix ??


Fig. 3. Difference amplifier with a gain of R4/R3

VAmplif ied signal =

R4
R3
- (VLM 35 − VOf f set voltage) (5)

Then, to achieve clipping, two components are used. A diode to eliminate negative voltages and a 9V Zener diode in clipping configuration to limit the voltage level to 9V . The configuration can be seen in Figure 21. When the temperature level is below the 24◦C, the amplified signal obtained from the difference amplifier is negative. Then, the diode does not allow any current flow on it resulting in 0V in its other end. When it is larger than 9 V, the Zener diode clips the voltage across is to 9V . The ratio of the resistance values are taken to be high in order to not lose the amplified signals value on the resistor series to it much.


Fig. 4. Clipping circuit

Vsensing clipped = (VAmplif ied signal − VD1 ON )·(

R6
R5 + R6

)

(6)
Consider R5 << R6 and VAmplif ied signal = VAS;

Vsensing clipped =

0 | if VAS < VD1 ON
VZ2 | if VAS − VD1 ON > VZ2
VAS − VD1 ON | if Otherwise
(7)
Then, this voltage is again fed to a voltage buffer, and the output of the buffer is the overall output of this unit which is denoted as Vsensing. The change in the output voltage with respect to the ambient temperature is given in equation 8
Vsensing = 0.56(Cambient − 24)V | (8)

Apart from the function of the system, some LED lights are added to the circuit to verify the correct operation. To observe the output voltage level without affecting the circuit in Figure ?? is used where the current through the LED is controlled by the output voltage level. This allows to check the output voltage level by observing the LED lights intensity.


Fig. 5. Buffering Vsensing clipped, and Vsensing magnitude indicating

Vsensing = Vsensing clipped | (9)

IRED LED T emperature =

Vsensing
R7

(10)

So by combining equations xxxxxx,

A + B + C + D + E + F + G + H + I + J + K + L + M + N + O + P + Q + R + S + T + U + V + W + X + Y + Z
(11)

Vsensing =

R4
R3
- (VLM 35 − VOf f set voltage)·

(12)

Also, the DC power supply terminals are connected to LED lights through resistors to verify the proper connection of those terminals. Configuration of this part can be seen in Figure ??.


Fig. 6. +12V, GND and -12V indicator LEDs


Fig. 7. Designed (a) & assembled (b) PCBs of the sensing unit.

B. Set Unit

Set unit is where the user specifies the desired temperature. This unit is responsible of converting the desired temperature level into a voltage signal which to be compared with the sensing units output. To achieve this, a basic circuit with a potentiometer is utilized. User can control the knob of the potentiometer until the desired temperature level’s color is observed at the display unit. Since the sensing unit gives output between the 0 and 9V , same voltage range should be available in the set unit either. To achieve this, the circuit in the Figure 8 is designed. The output voltage level is taken from the middle leg of the potentiometer. This assures a linear increase in the voltage level when the knob is turned. Ideally, 0V output voltage is wished when the potentiometer gives 0Ω between its middle and lower legs. Hence the R? resistance should be chosen 0. But, to compensate for possible unidealities in the sensing units output voltage, minimum output voltage of this unit is chosen to be 0.25V . Similarly, maximum output voltage is chosen to be 8.75V . Hence the resistance values are chosen accordingly. The opamp is used as a buffer for isolation purposes. Similar to the sensing unit, the relation between the output of this unit and the set temperature is given in the equation 13.

Vset = 0.56(Cset − 24)V | (13)


Fig. 8. Schematic of the set unit


Fig. 9. LTspice model of the set unit


Fig. 10. LTspice simulation results of the set unit


Fig. 11. Assembled set unit

C. Control Unit

Control unit is where the signals from the set and sensing units are compared and the corresponding action ,heating or cooling, is determined. This unit takes two inputs Vsensing and Vset and produces two outputs Vheating and Vcooling. The desired relation between these signals are given in the Table II where Vrest and Voperate are chosen to be 0 and 12V respectively.

TABLE I
INPUT OUTPUT RELATIONS OF THE CONTROL UNIT
Vsensing − Vset | > 0 | < 0 | = 0
Vheater | Vrest | Voperate | Vrest
Vcooler | Voperate | Vrest | Vrest

First step of this unit is taking the difference of the Vset and Vsensing. A difference amplifier in Figure ?? can be used for this action. While making the subtraction, the resistance values are chosen to give a gain of 18.8. Using this gain and 8 and 13, the relation between Vset − Vsensing and the temperature difference between the ambient and set temperature reduces to the equation 14 which means each 10V in the output voltage of the difference amplifier corresponds to 1

◦C difference between
the ambient and set temperatures which is easy to work with.
Vset − Vsensing = 10(Cset − Csensing)V | (14)

To obtain the relation in table II from the output of the difference amplifier, a comparator should be utilized. But using a basic comparator can make the system vulnerable for oscillations between heating and cooling operations. Hence, schmitt trigger topology is chosen to apply. Schmitt trigger is a circuit topology that can be implemented with an opamp which has the vin vs vout characteristics in Figure 12.


Fig. 12. Schmitt trigger

A normal comparator characteristics has a change in the output voltage at just one point which makes it unstable around that input voltage value. This characteristics does not have that problem since it requires VIH amount of input voltage to have VOH amount of output voltage but the output voltage does not change unit the input voltage is reduced to VIL. Circuit implementation of the schmitt trigger is given in Figure ?? Here, by substituting the output voltage of the difference amplifier as the input value, the resistance values can be chosen such that the output voltage???? Here, Vref is ??. Desired Vref can be obtained from the circuit in Figure ??. This circuit is very similar to the one used at the sensing unit to obtain the offset voltage in Figure 2. There is a zener diode to suppress the oscillations in the power supply and a voltage divider circuit between its tips. The resistance values are chosen to give ??V as the reference voltage.
As a last step, circuit in Figure ?? is used. The output of the schmitt trigger is passed through a diode and connected to the ground through a resistor to make the negative voltages
0. Also, the output from the diode is connected to a red led to indicate the operation element is working. As can be seen from the Figure ??, voltage at the tip of the diode is the overall output.
Note that there are two circuits in this unit. Output of one of which is producing Vheating and the other one is producing Vcooling. The diagram of both of these circuits are the same and explained above except for the subtraction direction in the difference amplifier. For Vheating, Vsensing is subtracted from the Vset as explained above. For Vcooling, Vset is subtracted from the Vsensing.


Fig. 13. Designed (a) & assembled (b) PCBs of the control unit.

D. Operation Unit: Heating and Cooling

Operation unit is isolating the power circuitry from the rest of the design. It is responsible for conducting the specified operation by the control unit. This unit has two input terminals corresponding to the output terminals of the control unit for heating and cooling operation.As explained in the related section, control unit sends Voperate = 5V for the operation it wants to take place and Vrest = 0V for the one it does not. Hence, this unit should act like a switch for the heating and cooling elements which is on when the input is 5V and off when it is 0V . As the heating element, nickel-chromium resistance wire is used. This choice was made due to low heat capacity of this element which allows fast starting and finishing heating. As the cooling element, 9V DC computer case fan is used. The heating and cooling circuits are two separate circuits having one input but their configurations are the same except the operation element used. In this circuit configuration, first, the input voltage is transferred using a voltage buffer for isolation purposes. Then the output of the voltage buffer is fed into the gate of a MOSFET whose drain is connected to the voltage supply through the heating/cooling element. The source of the MOSFET is connected to the ground. A large resistance between the ground and source terminals of the MOSFET is connected. This resitor is put for reliability issues, it stabilizes the amplifier. The MOSFET has opening VGS,op voltage as ???V This is compatible with the possible input voltage values. Since VGS,op is fairly bigger than Voperate and smaller than Vrest, small discrepancies will not affect the operation of the circuit. Also, another resistance is added between the input signal and the ground to avoid a floating end when the input signal is not connected. When Voperate is supplied, the MOSFET is out of the cut-off region. Hence, drain current is allowed to flow on it. Since the drain of the MOSFET is connected to the operation element, the operation element works for this case. When Vrest is supplied, the MOSFET is in the cut-off region. Hence, drain current is not allowed to flow and the operation element does not work. The overall structure can be seen in Figure 14
add figure here


Fig. 14. Schematic of the operation unit

TABLE II
ELECTRICAL CHARACTERISTICS OF FAN AND HEATER
Unit Name | Current(mA) | Voltage Drop (V) | Power(W)
Fan simulated | 150 | 12 | 1.8
Fan practical | 78 | 12 | 0.94
Heater simulated | 500 | 12 | 6
Heater practical | 620 | 12 | 7.4

Fig. 15. Input current & input voltage characteristics of the system when neither fan nor heater is working (a), fan is working (b), heater is working (c)


Fig. 16. Driver (a) and operation (b) parts of the operation unit.

E. Display Unit
The aim of the display unit is to observe the desired and ambient temperature levels in a color spectrum in an analog manner given in the Figure 17. Input of this unit is both Vset and Vsensing. But only one of the input is considered at a time. A switch is utilized to transit between ambient and set temperature levels. In the remaining of this section, only ambient temperature will be discussed to ease the notations. It should be noted that, same operation applies to the set temperature when the swith is in the corresponding position. To achieve a continuous color spectrum, an RGB led is utilized. RGB led has three legs corresponding to blue, green and red led lig!hts whose intensities can be controlled by the current passing through them. RGB led has two versions: common cathode and common anode. [2] *niye common cathode sec¸ildigini ac¸ıkla ˘


Fig. 17. Color spectrum for the display unit

Since the current and intensity of the led lights are directly proportional, current through each three led versus the temperature graphs should be as the Figure ??. To achieve this pattern for the red led leg, first, the circuit in Figure 18 is designed. What this circuit does it to produce a voltage level, denoted by Vred. Later, voltage level will be fed to the base terminal of a BJT through a resistor to control the current entering the collector terminal of the BJT. The circuit in Figure 18 consists of a difference amplifier, a diode and a pull down resistor to eliminate the output when it is negative and a led to verify the positive output voltage. By using the equations 8 and 13 and inserting this into the Figure 15’s temperature axis it can be seen that red led should not allow any current when the input voltage (Vsensing) is less than 4.5V . Hence, the reference value to be substracted from the input should be 4.5V . Output Vred voltage of this circuit is given in the equation 15.

Vred =

(
R?
R?

(Vin − Vref − 0.5Vdiode) if Vred > 0
0 | o. w.

(15)


Fig. 18. Color spectrum for the display unit

A similar logic can be applied to obtain a Vblue voltage. This time blue led should not allow any current when the input voltage (Vsensing) is more than 4.5V . Hence, the circuit in the Figure 19 is constructed to obtain Vblue to be fed to the base terminal of a BJT. In this circuit everything is the same with the circuit in Figure 18 expect the direction of the subtraction in the difference amplifier. Output Vblue voltage of this circuit is given in the equation 16.

Vblue =

(
R?
R?

(Vref − Vin − 0.5Vdiode) if Vblue > 0
0 | o. w.

(16)


Fig. 19. Color spectrum for the display unit

For the current going through the green leg, we do not have a zero current region like in the blue and red legs, hence, it is difficult to implement that current level in a similar manner. But note that, the total amount of current flowing through the all three legs are equal for all temperatures. Hence current through the red leg can be computed as Iref − Ired − Iblue where Ired and Iblue are denoting the current through the blue and red legs respectively and the Iref can be found in Figure ??.For this purpose, the circuit in the Figure ?? is constructed. This circuit acts like an ideal current source with value curentvalueintermsofR. The final circuitry of this unit can be seen in Figure 20. As explained before, Vred and Vblue voltages are fed to a base of a BJT whose emitter is connected to the ground and collector is collected to the red and green legs of the RGB led. This configuration provides a linear increase in the collector current with respect to the Vred and Vblue. Here, R22 is chosen such that 15mA of current will pass the collector of Q1 when then Vred = 10V . A similar choice of R29 is also valid. With supplying the reference current value to the overall RGB, current through the green leg is arranged. Here, it should be noted that there are actually two voltage drops on Vred and Vblue. First one is coming from the opening voltage of the diode in Figures ?? and ?? which are also explained in the equations 16 and 15. Second one is the opening voltage of the BJT in the Figure 20. Hence, with the 4.5 V of reference voltage is not enough, the reference voltages should be determined so that these voltage drops are taken into account.
*kullanılan mosfet ve opamp c¸es¸itlerini belirt
*opampte iki opamp oldugunu belirt ˘
*simulation results
*experimental results
The input output relations of the units can be seen in Figure 22.

IV. CONCLUSION

REFERENCES

[1]


Fig. 20. Color spectrum for the display unit


Fig. 21. Designed (a) & assembled (b) PCBs of the display unit.


Fig. 22. Color spectrum for the display unit

[2]

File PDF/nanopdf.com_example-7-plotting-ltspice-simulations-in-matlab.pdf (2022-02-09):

Example 7 – Plotting LtSpice Simulations in Matlab
In LtSpice, after doing a simulation you can save the data which was used to generate the simulation and import it into MATLAB for further manipulation. Matlab has a loadfile command that allows such files (with minor modification) to be read into Matlab and operated on using Matlab's functions.
There are two advantages to reading LtSpice files into Matlab. First Matlab creates "prettier" reports and graphs that are easier to integrate into Word. Second Matlab can do many functions that can't be done easily in LtSpice and this gives you an opportunity to enrich you simulation.
In this example, we will do a simulation in LtSpice, save the file, modify it for reading into Matlab, and finally read it into Matlab to make a plot.
We begin by constructing the circuit in Figure E7-1 using LtSpice. The simulation looks at Vin and Vout


Figure E7-1
Circuit for simulation in Workbench.
After the simulation runs click once on the plot and select File → Export. This will bring up a screen shown in Figure E7-2. Select a path and file name and click OK to save the data as a text file. You can exit LtSpice


Figure E7-2
The File→Export menu from LtSpice
The saved file is a simple text file that you can open and examine using Notepad or Word. The file consists of some header information followed by three columns of data giving the time base and the corresponding voltage levels for the two nodes. Figure E7-3 shows the beginning and end of this file.
time V(n002) | V(n003)
0.000000000000000e+000 0.000000e+000 | 0.000000e+000
1.896585271020485e-009 -1.779854e-006 | 2.383319e-005
3.793170542040970e-009 -7.007942e-006 | 4.766639e-005
5.689755813061455e-009 -1.568426e-005 | 7.149958e-005
7.586341084081940e-009 -2.780881e-005 | 9.533277e-005
9.482926355102426e-009 -4.338160e-005 | 1.191660e-004
1.137951162612291e-008 -6.240262e-005 | 1.429992e-004
1.327609689714339e-008 -8.487187e-005 | 1.668324e-004
2.556419391731497e-008 -3.034966e-004 | 3.212491e-004
4.418355913658504e-008 -8.520387e-004 | 5.552270e-004
…
1.998464199406124e-001 -7.143645e-001 | -1.640545e+000
1.998609112380335e-001 -8.052113e-001 | -1.529819e+000
1.998787348420469e-001 -9.070134e-001 | -1.375973e+000
1.998980380558890e-001 -1.004364e+000 | -1.190083e+000
1.999218366406368e-001 -1.103188e+000 | -9.370503e-001
1.999502564861356e-001 -1.186708e+000 | -6.086052e-001

1.999903189323086e-001 -1.250910e+000 | -1.206329e-001
2.000000000000000e-001 -1.249292e+000 | 1.571833e-014
Figure E7-3
The exported data file opened using Notepad.
Matlab can read text files using the load 'filename' command. However, Matlab expects these files to contain only the data and not any header information. If we try to read the exported text file with Matlab's load command we will generate an error. To correct this we modify the file by deleting all of the header information from the top of the file down to the first line of data. The first line of the file should read
0.000000000000000e+000 0.000000e+000 0.000000e+000
Save this amended file with a new name such as Ex7.txt. Ex7.txt can now be read into Matlab and stored as a vector having one row for each row in the file and three columns. Figure E7-4 shows an m-file that reads Ex7.txt into a variable called "scope". We then use the colon operator to separate the scope vector into two new vectors called ChA and ChB. ChA contains the time base in column 1 and the channel A scope data in column 2. ChB contains the time base in column 1 and the channel B scope data in column 2. Both can then be plotted. Figure E7-4 shows the results of the plot.
%Example7.m
scope = load('Ex7.txt');
ChA = [scope(:,1),scope(:,2)]; ChB = [scope(:,1),scope(:,3)]; figure(1);clf;
subplot(2,1,1);
plot(ChA(:,1),ChA(:,2));
axis([0 .02 -1.2 1.2]);
subplot(2,1,2);
plot(ChB(:,1),ChB(:,2));
axis([0 .02 -2.2 2.2]);
Figure E7-3

This m-file loads a text file named 'Ex7.txt' into a variable called scope. The variable is then separated into two variables called ChA and ChB and the data for each channel is plotted. Figure E7-4 shows the results of the plot.

Figure E7-4

The Matlab plotted results from the LtSpice simulation.

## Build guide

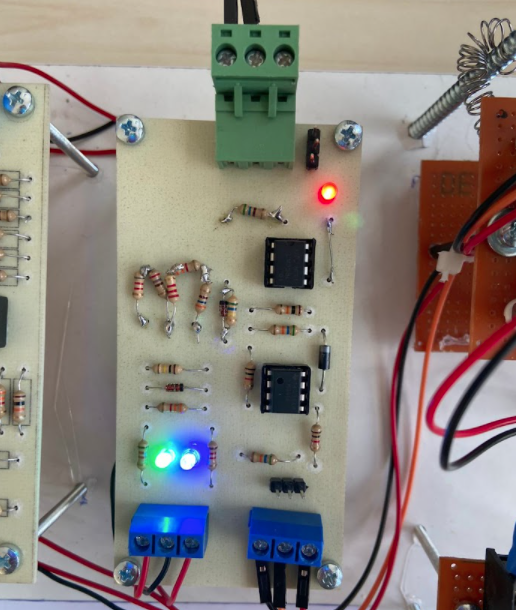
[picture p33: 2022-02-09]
Pictures/Sensing Unit/assembled.png

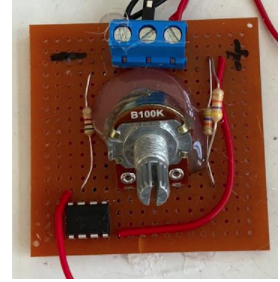
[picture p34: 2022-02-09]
Pictures/Set unit/assembled set unit.png

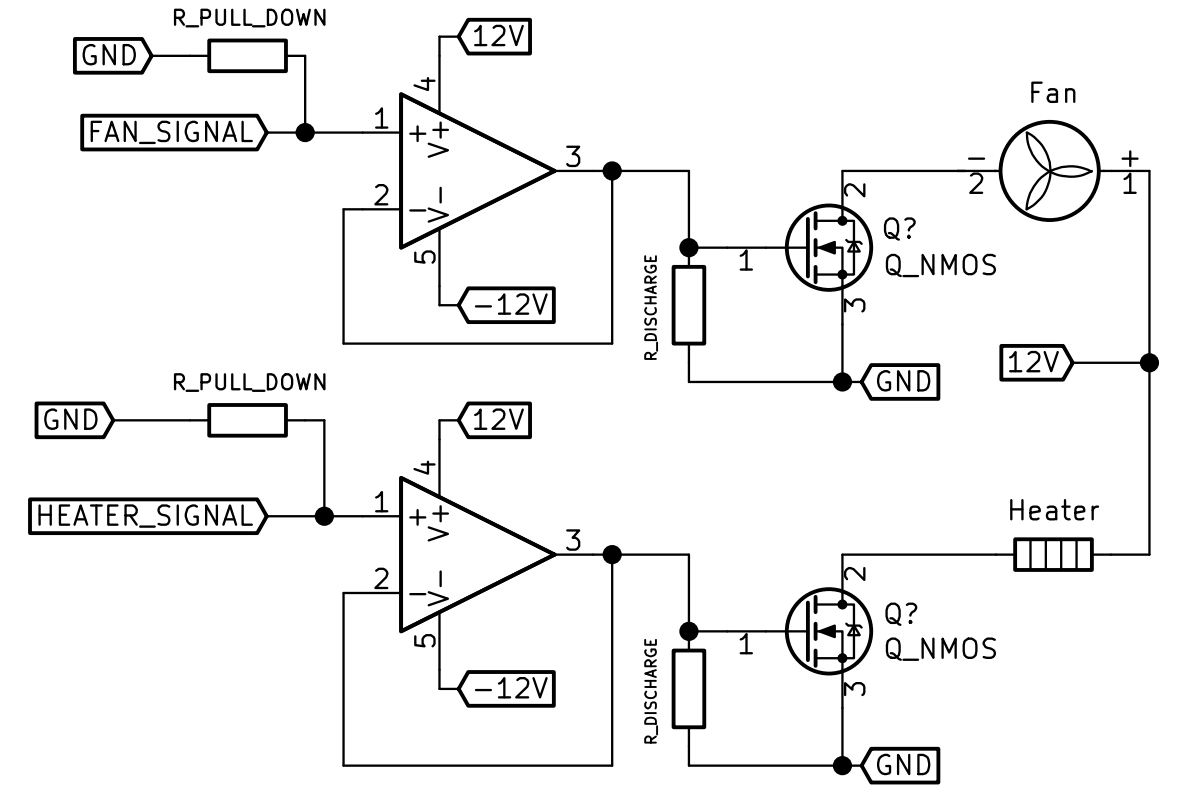
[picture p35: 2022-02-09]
Pictures/operation unit/operation unit schematic.png

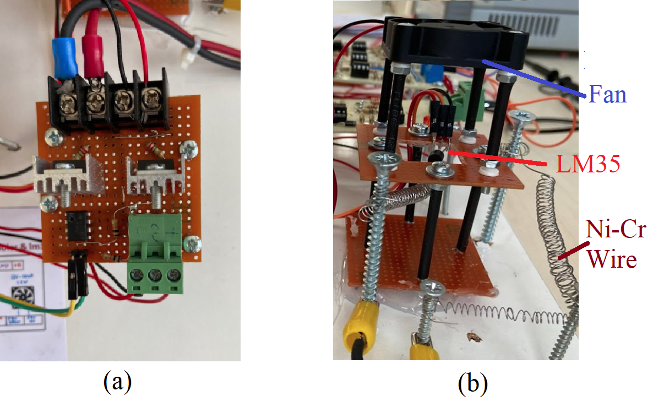
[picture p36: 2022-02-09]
Pictures/operation unit/assembled.png

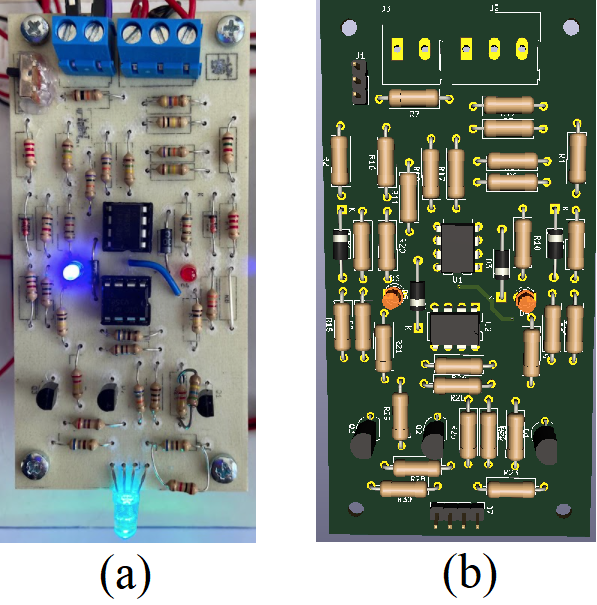
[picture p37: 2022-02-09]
Pictures/display unit/assembled and designed.png

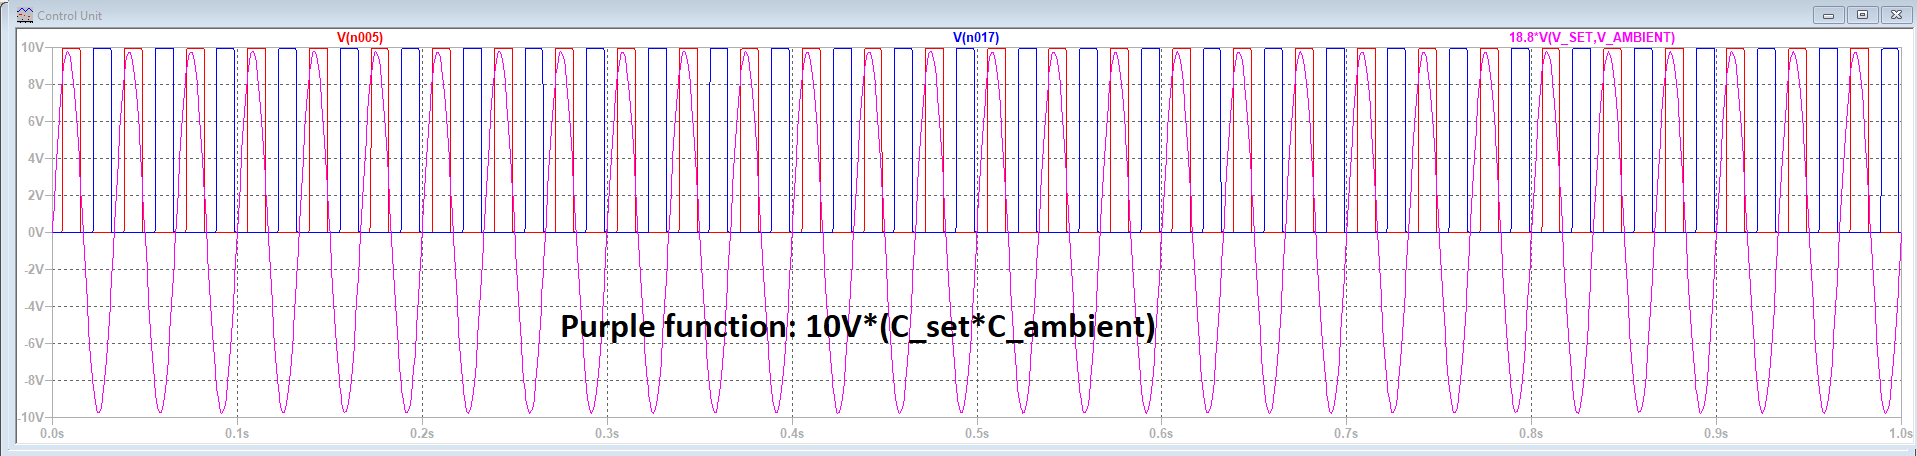
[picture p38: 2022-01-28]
Simulation/Control Unit - 4/operation graph with temeprature difference less than 1C.png

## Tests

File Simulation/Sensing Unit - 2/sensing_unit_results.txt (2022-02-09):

0.000000000000000e+000	-2.793422e-002	0.000000e+000
2.000000000000000e-001	-2.793422e-002	0.000000e+000
2.212534324128944e-001	-2.794156e-002	3.542239e-001
2.425068648257888e-001	-2.794404e-002	7.084477e-001
2.637602972386832e-001	-2.794165e-002	1.062672e+000
2.850137296515776e-001	-2.793439e-002	1.416895e+000
3.062671620644720e-001	-2.792227e-002	1.771119e+000
3.275205944773664e-001	-2.790528e-002	2.125343e+000
3.487740268902607e-001	-2.788343e-002	2.479567e+000
3.497505893902607e-001	-2.770446e-002	2.495843e+000
3.507271518902607e-001	-2.690399e-002	2.512119e+000
3.517037143902607e-001	-2.434611e-002	2.528395e+000
3.524106149743309e-001	-1.980291e-002	2.540177e+000
3.530341851373289e-001	-1.233857e-002	2.550570e+000
3.536691558300549e-001	-1.601471e-003	2.561153e+000
3.538740297710412e-001	2.538834e-003	2.564567e+000
3.538818207495323e-001	2.710052e-003	2.564697e+000
3.538974027065145e-001	3.060003e-003	2.564957e+000
3.539285666204791e-001	3.767351e-003	2.565476e+000
3.539908944484081e-001	5.200240e-003	2.566515e+000
3.540425065503430e-001	6.402443e-003	2.567375e+000
3.540701875646348e-001	7.054763e-003	2.567836e+000
3.540863225357979e-001	7.437869e-003	2.568105e+000
3.540956476060607e-001	7.660200e-003	2.568261e+000
3.541010663221645e-001	7.789701e-003	2.568351e+000
3.541041782358486e-001	7.864218e-003	2.568403e+000
3.541059170193858e-001	7.906063e-003	2.568432e+000
3.541068205771650e-001	7.927887e-003	2.568447e+000
3.541075292665940e-001	7.944859e-003	2.568459e+000
3.541077547095234e-001	7.950204e-003	2.568462e+000
3.541080883181399e-001	7.958119e-003	2.568468e+000
3.541083263694215e-001	7.963781e-003	2.568472e+000
3.541085220472301e-001	7.968443e-003	2.568475e+000
3.541090250528856e-001	7.980451e-003	2.568484e+000
3.541097491511505e-001	7.997778e-003	2.568496e+000
3.541109879117720e-001	8.027468e-003	2.568516e+000
3.541122266723935e-001	8.057175e-003	2.568537e+000
3.541134654330149e-001	8.086898e-003	2.568558e+000
3.541147041936364e-001	8.116637e-003	2.568578e+000
3.541159429542579e-001	8.146392e-003	2.568599e+000
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

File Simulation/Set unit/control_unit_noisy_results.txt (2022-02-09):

0.000000000000000e+000	2.267234e-002	-1.100876e-006
1.581132065243937e-007	2.265269e-002	-1.100876e-006
3.162264130487875e-007	2.251737e-002	-1.100877e-006
4.743396195731813e-007	2.226639e-002	-1.100877e-006
6.324528260975750e-007	2.189973e-002	-1.100877e-006
7.905660326219687e-007	2.141742e-002	-1.100877e-006
9.486792391463625e-007	2.081943e-002	-1.100877e-006
1.106792445670756e-006	2.010578e-002	-1.100877e-006
1.988778522732485e-006	1.500615e-002	-1.100878e-006
2.998421350464264e-006	7.058126e-003	-1.100880e-006
4.084011293997274e-006	-3.569872e-003	-1.100882e-006
5.140284089392240e-006	-1.554368e-002	-1.100884e-006
6.657838008740953e-006	-3.464060e-002	-1.100888e-006
8.805940607545673e-006	-6.369632e-002	-1.100894e-006
1.140297674783288e-005	-1.005521e-001	-1.100901e-006
1.459105548710395e-005	-1.470221e-001	-1.100911e-006
3.288593499530018e-005	-4.163460e-001	-1.100966e-006
4.813183382610047e-005	-6.360091e-001	-1.101012e-006
7.862363148770105e-005	-1.052886e+000	-1.101100e-006
1.274517564877010e-004	-1.650329e+000	-1.101228e-006
1.762798814877010e-004	-2.148737e+000	-1.101337e-006
2.068562974167693e-004	-2.391128e+000	-1.101390e-006
2.281503399066087e-004	-2.517301e+000	-1.101418e-006
2.447562022329676e-004	-2.589591e+000	-1.101434e-006
2.630503814640291e-004	-2.642428e+000	-1.101446e-006
2.862409922768981e-004	-2.668814e+000	-1.101452e-006
3.238156053796835e-004	-2.627564e+000	-1.101443e-006
3.726437303796835e-004	-2.462607e+000	-1.101406e-006
4.039783565794073e-004	-2.288933e+000	-1.101367e-006
4.442668529615555e-004	-1.997268e+000	-1.101303e-006
4.828990360448417e-004	-1.680474e+000	-1.101234e-006
5.285797861518663e-004	-1.291982e+000	-1.101151e-006
5.774079111518664e-004	-9.061584e-001	-1.101069e-006
6.262360361518664e-004	-5.967422e-001	-1.101004e-006
6.750641611518664e-004	-3.929271e-001	-1.100962e-006
7.072297820627593e-004	-3.290674e-001	-1.100948e-006
7.229958115133549e-004	-3.283698e-001	-1.100948e-006
7.408403726456530e-004	-3.553567e-001	-1.100954e-006
7.615923597396365e-004	-4.159597e-001	-1.100966e-006
7.838696156194645e-004	-5.204736e-001	-1.100988e-006
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

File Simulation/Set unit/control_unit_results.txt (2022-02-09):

0.000000000000000e+000	2.267234e-002	-1.100876e-006
3.806344606211401e-007	2.259067e-002	-1.100876e-006
7.612689212422802e-007	2.240872e-002	-1.100877e-006
1.141903381863420e-006	2.212651e-002	-1.100877e-006
1.522537842484560e-006	2.174403e-002	-1.100877e-006
1.903172303105701e-006	2.126128e-002	-1.100877e-006
2.283806763726840e-006	2.067826e-002	-1.100877e-006
2.664441224347980e-006	1.999497e-002	-1.100877e-006
3.896032635584828e-006	1.761072e-002	-1.100877e-006
5.575466508703116e-006	1.366074e-002	-1.100878e-006
7.285128532202357e-006	9.139730e-003	-1.100879e-006
9.618078903792701e-006	2.505893e-003	-1.100881e-006
1.190340945321542e-005	-4.256667e-003	-1.100882e-006
1.512095982837133e-005	-1.399251e-002	-1.100884e-006
2.625433609496552e-004	-7.728312e-001	-1.101041e-006
3.546055428279584e-004	-1.054891e+000	-1.101100e-006
4.466677247062616e-004	-1.335436e+000	-1.101160e-006
5.387299065845647e-004	-1.614468e+000	-1.101220e-006
6.307920884628679e-004	-1.891985e+000	-1.101280e-006
7.228542703411711e-004	-2.167988e+000	-1.101341e-006
8.149164522194744e-004	-2.442478e+000	-1.101401e-006
9.069786340977773e-004	-2.715453e+000	-1.101463e-006
9.558067590977774e-004	-2.859062e+000	-1.101495e-006
1.053463009097777e-003	-3.144212e+000	-1.101560e-006
1.102291134097777e-003	-3.285685e+000	-1.101593e-006
1.151119259097777e-003	-3.426380e+000	-1.101625e-006
1.234239071835076e-003	-3.664189e+000	-1.101680e-006
1.359938782577928e-003	-4.020053e+000	-1.101764e-006
1.485638493320781e-003	-4.368272e+000	-1.101847e-006
1.611338204063634e-003	-4.708844e+000	-1.101929e-006
1.737037914806487e-003	-5.041771e+000	-1.102010e-006
1.862737625549339e-003	-5.367053e+000	-1.102090e-006
1.988437336292192e-003	-5.684688e+000	-1.102170e-006
2.114137047035045e-003	-5.994678e+000	-1.102248e-006
2.169707145674913e-003	-6.128419e+000	-1.102282e-006
2.225277244314782e-003	-6.260155e+000	-1.102315e-006
2.280847342954651e-003	-6.389887e+000	-1.102348e-006
2.336417441594519e-003	-6.517614e+000	-1.102381e-006
2.391987540234388e-003	-6.643337e+000	-1.102414e-006
2.447557638874257e-003	-6.767055e+000	-1.102446e-006
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

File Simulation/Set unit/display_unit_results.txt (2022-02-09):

0.000000000000000e+000	0.000000e+000	1.051550e-011	2.177038e-011	1.395803e-002
1.283566106842308e-006	1.155210e-004	1.051553e-011	2.156915e-011	1.395803e-002
2.567132213684616e-006	2.310419e-004	1.051557e-011	2.141871e-011	1.395803e-002
3.850698320526923e-006	3.465629e-004	1.051562e-011	2.131906e-011	1.395803e-002
5.134264427369231e-006	4.620838e-004	1.051567e-011	2.127022e-011	1.395803e-002
6.417830534211539e-006	5.776048e-004	1.051572e-011	2.127216e-011	1.395803e-002
7.701396641053846e-006	6.931257e-004	1.051578e-011	2.132490e-011	1.395802e-002
8.984962747896151e-006	8.086467e-004	1.051584e-011	2.142844e-011	1.395802e-002
2.631239915082634e-003	2.368116e-001	1.057138e-011	2.142864e-011	1.395550e-002
5.253494867417372e-003	4.728146e-001	1.062234e-011	2.142889e-011	1.395246e-002
7.875749819752108e-003	7.088175e-001	1.066872e-011	2.142918e-011	1.394889e-002
1.049800477208685e-002	9.448205e-001	1.071051e-011	2.142950e-011	1.394479e-002
1.312025972442158e-002	1.180823e+000	1.074771e-011	2.142987e-011	1.394016e-002
1.574251467675632e-002	1.416826e+000	1.078033e-011	2.143028e-011	1.393501e-002
1.836476962909105e-002	1.652829e+000	1.080837e-011	2.143073e-011	1.392934e-002
1.949479195051964e-002	1.754531e+000	1.082557e-011	2.143094e-011	1.392665e-002
2.062481427194823e-002	1.856233e+000	1.085300e-011	2.143120e-011	1.392337e-002
2.175483659337682e-002	1.957935e+000	1.089067e-011	2.143150e-011	1.391950e-002
2.288485891480541e-002	2.059637e+000	1.093856e-011	2.143184e-011	1.391502e-002
2.401488123623399e-002	2.161339e+000	1.099669e-011	2.143223e-011	1.390995e-002
2.514490355766258e-002	2.263041e+000	1.106505e-011	2.143267e-011	1.390428e-002
2.627492587909117e-002	2.364743e+000	1.114364e-011	2.143315e-011	1.389801e-002
2.673530534337689e-002	2.406177e+000	1.117746e-011	2.143336e-011	1.389520e-002
2.719568480766261e-002	2.447612e+000	1.122915e-011	2.143362e-011	1.389173e-002
2.765606427194833e-002	2.489046e+000	1.129870e-011	2.143393e-011	1.388759e-002
2.811644373623405e-002	2.530480e+000	1.138612e-011	2.143428e-011	1.388279e-002
2.857682320051977e-002	2.571914e+000	1.149140e-011	2.143469e-011	1.387733e-002
2.903720266480549e-002	2.613348e+000	1.161455e-011	2.143514e-011	1.387120e-002
2.949758212909121e-002	2.654782e+000	1.175557e-011	2.143563e-011	1.386441e-002
2.967894373623407e-002	2.671105e+000	1.181607e-011	2.143585e-011	1.386145e-002
2.986030534337693e-002	2.687427e+000	1.190388e-011	2.143611e-011	1.385777e-002
3.004166695051979e-002	2.703750e+000	1.201899e-011	2.143643e-011	1.385336e-002
3.022302855766265e-002	2.720072e+000	1.216139e-011	2.143679e-011	1.384822e-002
3.040439016480551e-002	2.736395e+000	1.233110e-011	2.143719e-011	1.384237e-002
3.058575177194837e-002	2.752718e+000	1.252812e-011	2.143765e-011	1.383579e-002
3.076711337909123e-002	2.769040e+000	1.275243e-011	2.143816e-011	1.382849e-002
3.096242587909123e-002	2.786618e+000	1.312813e-011	2.143889e-011	1.381755e-002
3.106008212909123e-002	2.795407e+000	1.338313e-011	2.143935e-011	1.381063e-002
3.115773837909124e-002	2.804196e+000	1.371014e-011	2.143989e-011	1.380223e-002
3.125539462909124e-002	2.812985e+000	1.414828e-011	2.144056e-011	1.379168e-002
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

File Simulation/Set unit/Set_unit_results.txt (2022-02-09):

1.000000000000000e+000	1.000000e+000	2.526689e-001
1.009990000000000e+002	1.009990e+002	2.610551e-001
2.009980000000000e+002	2.009980e+002	2.694414e-001
3.009970000000000e+002	3.009970e+002	2.778276e-001
4.009960000000000e+002	4.009960e+002	2.862138e-001
5.009950000000000e+002	5.009950e+002	2.946001e-001
6.009940000000000e+002	6.009940e+002	3.029863e-001
7.009930000000001e+002	7.009930e+002	3.113726e-001
8.009920000000001e+002	8.009920e+002	3.197589e-001
9.009910000000001e+002	9.009910e+002	3.281451e-001
1.000990000000000e+003	1.000990e+003	3.365314e-001
1.100989000000000e+003	1.100989e+003	3.449177e-001
1.200988000000000e+003	1.200988e+003	3.533040e-001
1.300987000000000e+003	1.300987e+003	3.616903e-001
1.400986000000000e+003	1.400986e+003	3.700766e-001
1.500985000000000e+003	1.500985e+003	3.784630e-001
1.600984000000000e+003	1.600984e+003	3.868493e-001
1.700983000000000e+003	1.700983e+003	3.952356e-001
1.800982000000000e+003	1.800982e+003	4.036220e-001
1.900981000000000e+003	1.900981e+003	4.120083e-001
2.000980000000000e+003	2.000980e+003	4.203947e-001
2.100979000000000e+003	2.100979e+003	4.287811e-001
2.200978000000000e+003	2.200978e+003	4.371675e-001
2.300977000000000e+003	2.300977e+003	4.455538e-001
2.400976000000000e+003	2.400976e+003	4.539402e-001
2.500975000000000e+003	2.500975e+003	4.623266e-001
2.600973999999999e+003	2.600974e+003	4.707131e-001
2.700972999999999e+003	2.700973e+003	4.790995e-001
2.800971999999999e+003	2.800972e+003	4.874859e-001
2.900970999999999e+003	2.900971e+003	4.958724e-001
3.000969999999998e+003	3.000970e+003	5.042588e-001
3.100968999999998e+003	3.100969e+003	5.126452e-001
3.200967999999998e+003	3.200968e+003	5.210317e-001
3.300966999999998e+003	3.300967e+003	5.294182e-001
3.400965999999998e+003	3.400966e+003	5.378047e-001
3.500964999999997e+003	3.500965e+003	5.461912e-001
3.600963999999997e+003	3.600964e+003	5.545776e-001
3.700962999999997e+003	3.700963e+003	5.629642e-001
3.800961999999997e+003	3.800962e+003	5.713507e-001
3.900960999999997e+003	3.900961e+003	5.797372e-001
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
1.000000000000000e+005	1.000000e+005	1.#QNAN0e+000

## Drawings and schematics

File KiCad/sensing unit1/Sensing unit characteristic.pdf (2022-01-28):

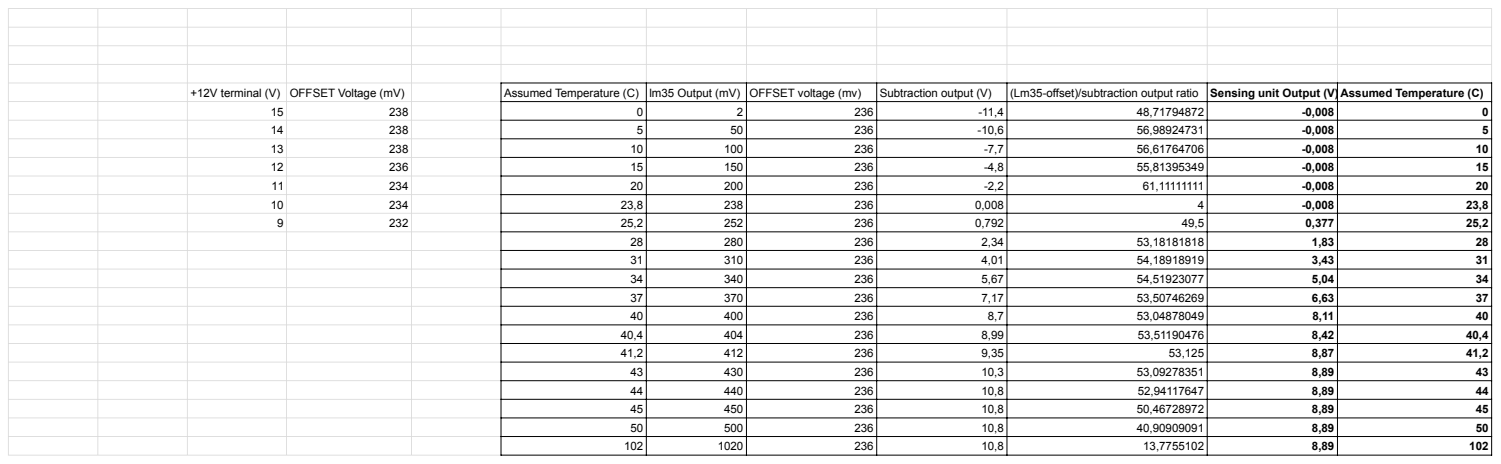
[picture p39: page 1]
+12V terminal (V) OFFSET Voltage (mV); Assumed Temperature (C); lm35 Output (mV); OFFSET voltage (mv); Subtraction output (V); (Lm35-offset)/subtraction output ratio; Sensing unit Output (V) Assumed Temperature (C)

28 | 280 | 236 | 2,34 | 53,18181818 | 1,83 | 28
31 | 310 | 236 | 4,01 | 54,18918919 | 3,43 | 31
34 | 340 | 236 | 5,67 | 54,51923077 | 5,04 | 34
37 | 370 | 236 | 7,17 | 53,50746269 | 6,63 | 37
40 | 400 | 236 | 8,7 | 53,04878049 | 8,11 | 40
40,4 | 404 | 236 | 8,99 | 53,51190476 | 8,42 | 40,4
41,2 | 412 | 236 | 9,35 | 53,125 | 8,87 | 41,2
43 | 430 | 236 | 10,3 | 53,09278351 | 8,89 | 43
44 | 440 | 236 | 10,8 | 52,94117647 | 8,89 | 44
45 | 450 | 236 | 10,8 | 50,46728972 | 8,89 | 45
50 | 500 | 236 | 10,8 | 40,90909091 | 8,89 | 50
102 | 1020 | 236 | 10,8 | 13,7755102 | 8,89 | 102

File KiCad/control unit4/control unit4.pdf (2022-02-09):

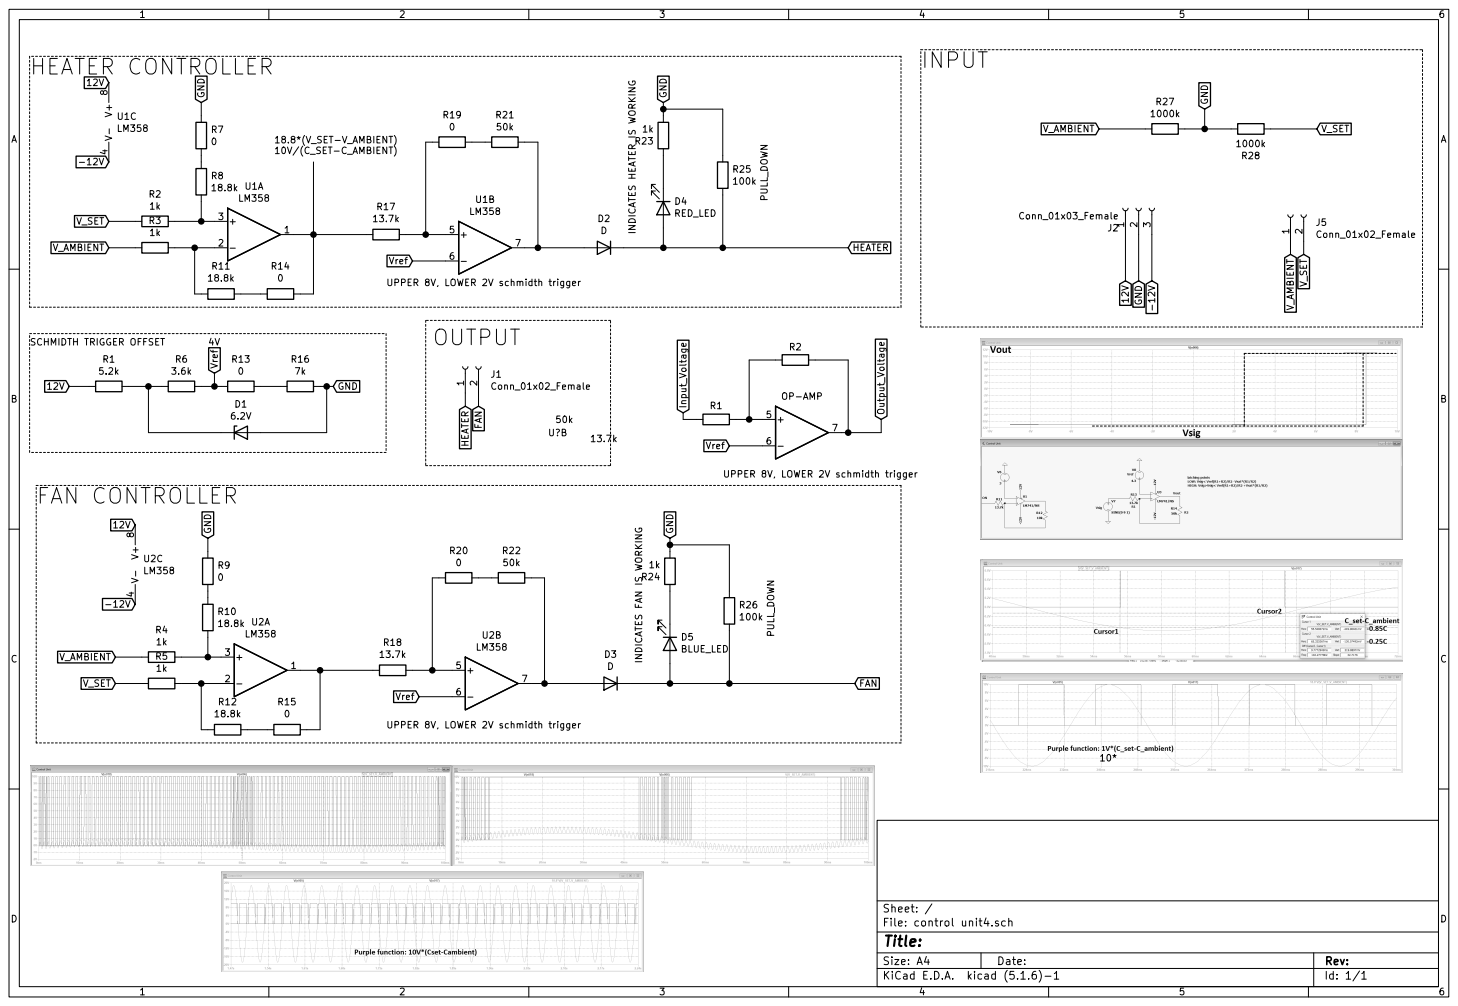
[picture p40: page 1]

UPPER 8V, LOWER 2V schmidth trigger
OUTPUT

Id: 1/1 Title: File: control unit4.sch Sheet: / +

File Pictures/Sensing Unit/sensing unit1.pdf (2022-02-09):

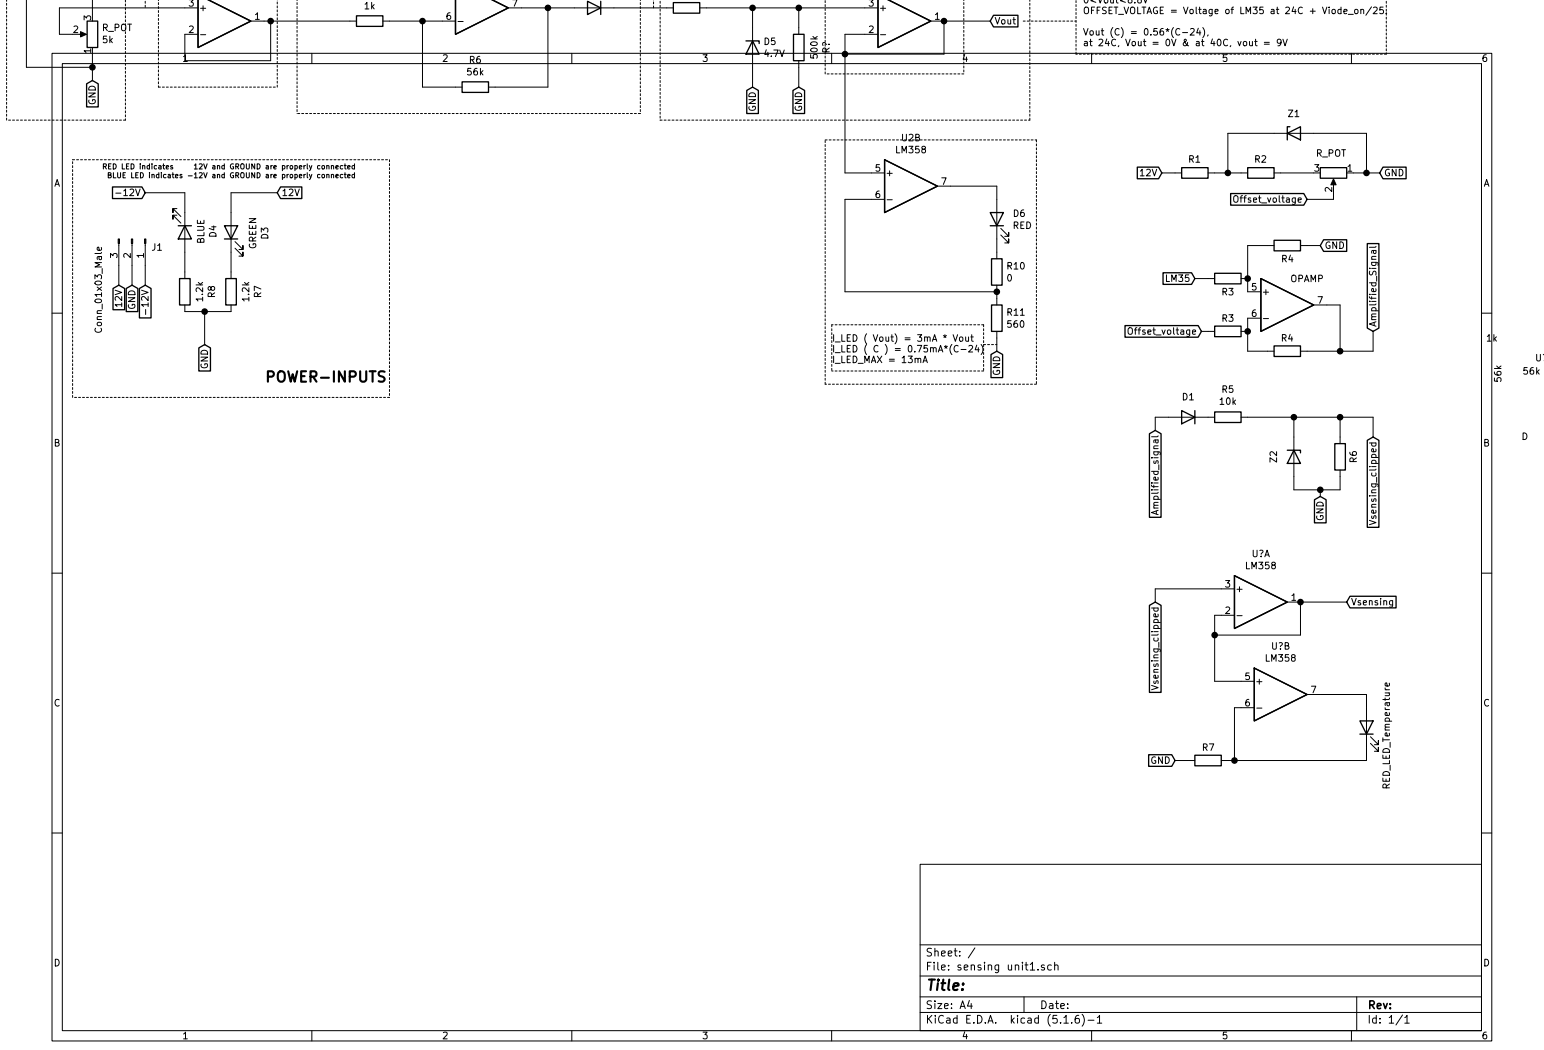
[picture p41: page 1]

0<Vout<8.8V OFFSET_VOLTAGE = Voltage of LM35 at 24C + Viode_on/25.

Vout (C) = 0.56*(C-24), at 24C, Vout = 0V & at 40C, vout = 9V

RED LED indicates 12V and GROUND are properly connected BLUE LED indicates -12V and GROUND are properly connected

File: sensing unit1.sch Sheet: / D3 GREEN

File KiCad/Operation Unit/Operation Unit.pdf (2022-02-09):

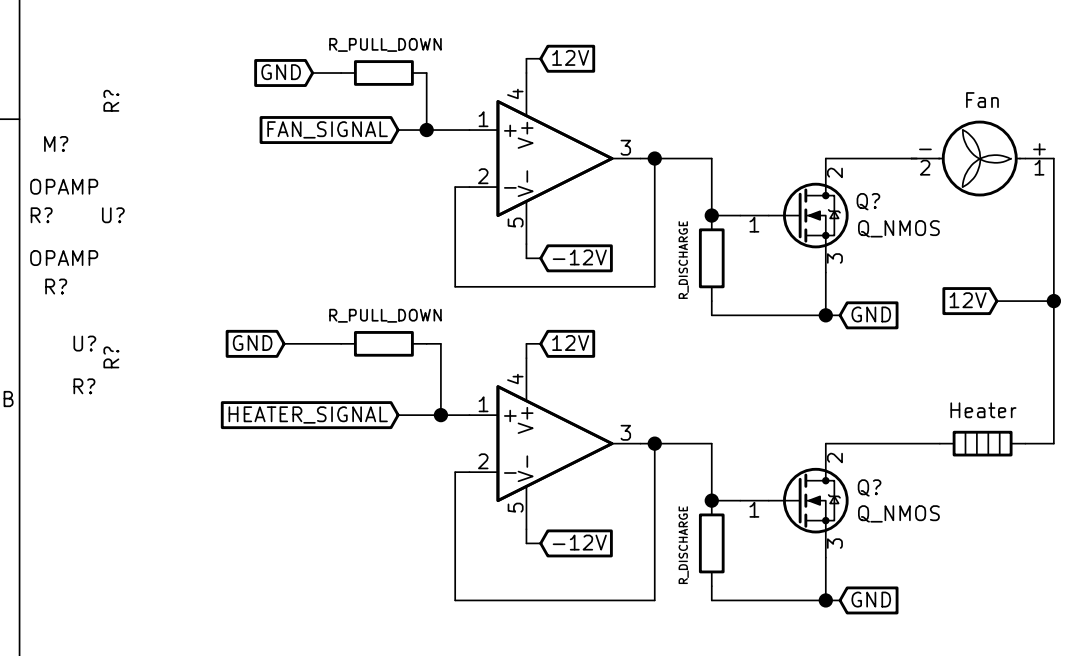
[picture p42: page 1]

File: Operation Unit.sch Sheet: /
Id: 1/1 Title:

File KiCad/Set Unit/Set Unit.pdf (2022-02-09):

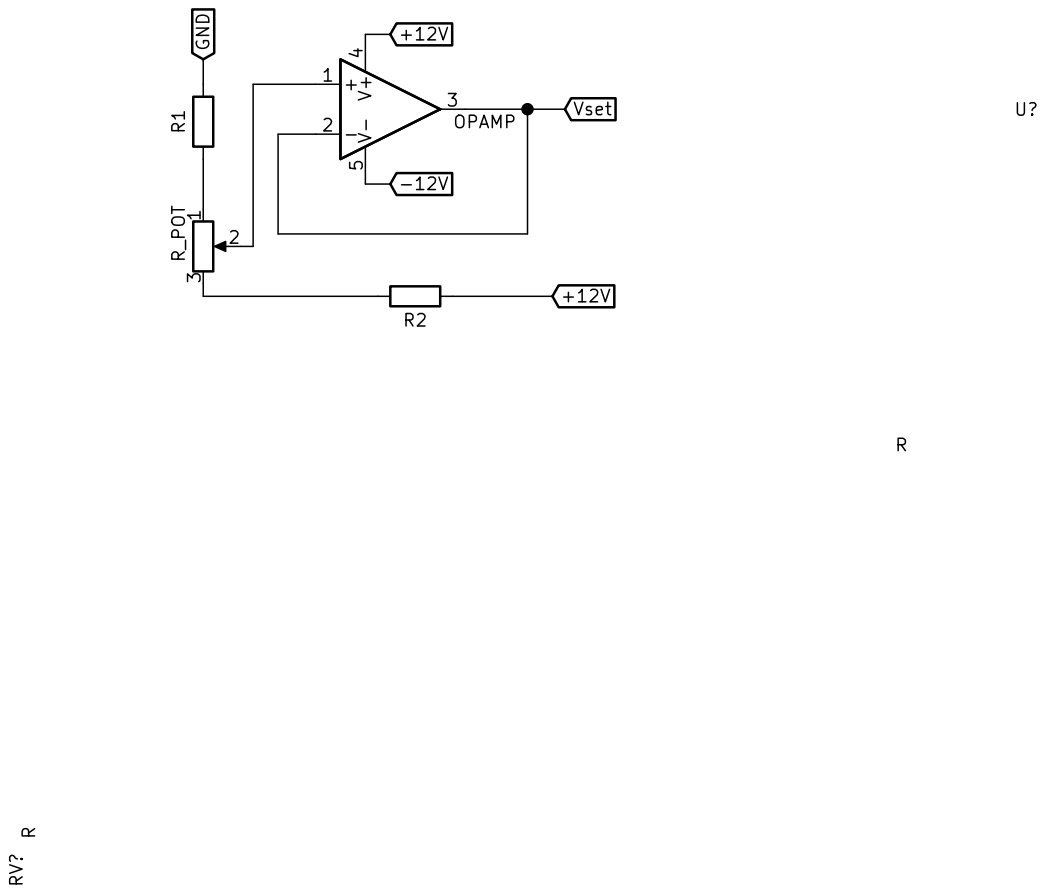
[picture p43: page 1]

Id: 1/1 Title: File: Set Unit.sch Sheet: / R1 R

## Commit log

2022-01-02 Temperature mapping
    [24C-40C] temperature range is mapped to [0,4.7V]
2022-01-15 PCB design for sensing unit
    .
    [sensing unit1.kicad_pcb, sensing unit1.sch]
2022-01-15 Sensing unit PCB
    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
    [sensing unit1.kicad_pcb]
2022-01-15 .
    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
    [sensing unit1.sch]
2022-01-28 cotrol unit4- schematic is finished
    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
    [control unit4.kicad_pcb, control unit4.sch]
2022-01-28 PCB of Control unit 4 is finished
    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
    [control unit4.sch]
2022-01-28 display unit3 simulation
    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
    [display unit2.kicad_pcb, display unit2.sch]
2022-01-28 display unit 3- schematic is finished
    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
    [display unit2.kicad_pcb, display unit2.sch]
2022-01-28 display unit 3 PCB is finished
    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
    [display unit2.sch]
2022-02-09 Final report is finished
    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
    [Operation Unit.kicad_pcb, Operation Unit.sch, Set Unit.kicad_pcb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]
